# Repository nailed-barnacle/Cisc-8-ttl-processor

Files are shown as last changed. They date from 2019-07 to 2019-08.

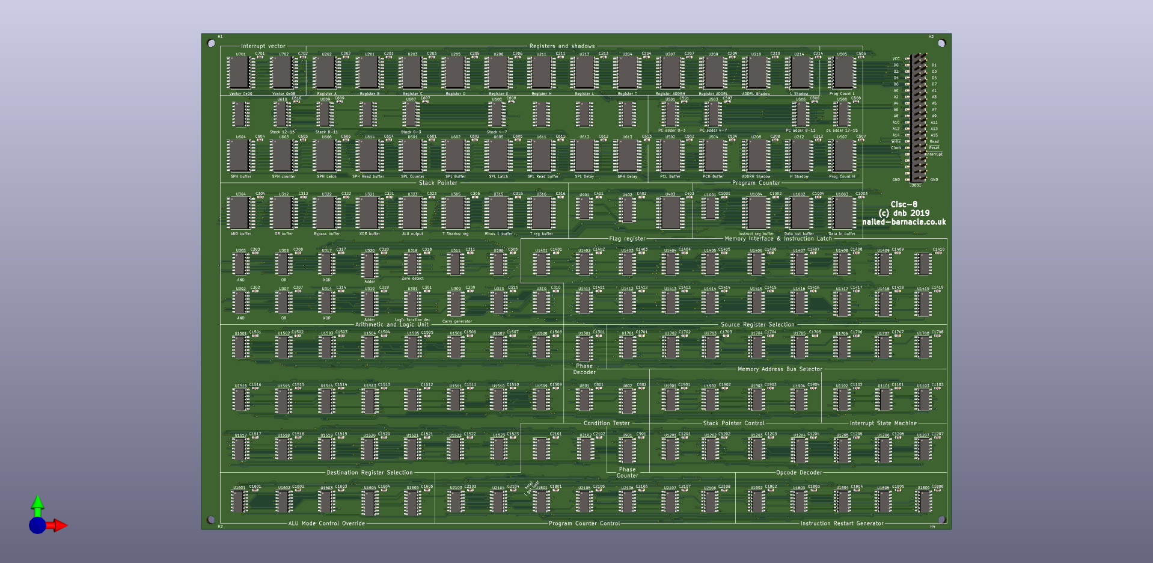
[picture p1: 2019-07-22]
cisc-8.png

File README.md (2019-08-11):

# Cisc-8-ttl-processor
A cut-down version of the 8080 processor using HCTTL and including a discrete ALU and instruction decoder

This is an attempt to replicate most of the functionality of the 1970s Intel 8080 processor using contemporary
HCTTL surface mount components.

By implementing most - though by no means all - of the instructions of the 8080 it allows the use of existing 
toolchains to generate code for the device both for the hardware implementation and the associated simulation.

The programmer's model is the same as the original 8080 - the following instructions are implemented (refer to an 8080 manual for details):

mov add adc sub sbb ana xra ora adi aci sui sbi ani xri ori sphl lxi dad lda sta mvi push pop jmp jnz jz jnc jc call ret 

All other instructions are unimplemented. There are minor changes regarding push/pull, in that push writes to the stack pointer address and then decrements it (and pull increments it and then reads) while the 8080 decrements before pushing. Additionally, it is not possible to mvi to m (hl).

A single non-maskable interrupt is provided, with a hard call to 0x0008 at the end of the current instruction (reset starts at 0x0000)

A two-internal bus model is used, which approximately doubles the speed (in clock cycles) of the original 8080. The longest instruction is the call, which requires 7 cycles.

Provided here are Kicad files for the schematics, Bill of Materials, and the final 200x300mm PCB. The normal
processor interface - data and address bus, power, clock etc are provided through a 40-pin header which would
attach to an adjacent board providing memory, serial port etc.

Recommended for assembling 8080 code in the browser: https://svofski.github.io/pretty-8080-assembler/

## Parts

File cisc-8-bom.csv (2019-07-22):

Source: | /home/barnacle/Projects/Cisc-8/Old/cisc-8 new/cisc-8.sch
Date: | Fri 28 Jun 2019 20:37:52 BST
Tool: | Eeschema 5.1.2-f72e74a~84~ubuntu18.04.1
Generator: | /usr/share/kicad/plugins/bom_csv_grouped_by_value.py
Component Count: | 311
Individual Components:
Item | Qty | Reference(s) | Value | LibPart | Footprint | Datasheet
 |  | C201 | 100n | cisc-8-rescue:C-Device | Capacitor_SMD:C_0603_1608Metric | ~
 |  | C202 | 100n | cisc-8-rescue:C-Device | Capacitor_SMD:C_0603_1608Metric | ~
 |  | C203 | 100n | cisc-8-rescue:C-Device | Capacitor_SMD:C_0603_1608Metric | ~
 |  | C204 | 100n | cisc-8-rescue:C-Device | Capacitor_SMD:C_0603_1608Metric | ~
 |  | C205 | 100n | cisc-8-rescue:C-Device | Capacitor_SMD:C_0603_1608Metric | ~
 |  | C206 | 100n | cisc-8-rescue:C-Device | Capacitor_SMD:C_0603_1608Metric | ~
 |  | C207 | 100n | cisc-8-rescue:C-Device | Capacitor_SMD:C_0603_1608Metric | ~
 |  | C208 | 100n | cisc-8-rescue:C-Device | Capacitor_SMD:C_0603_1608Metric | ~
 |  | C209 | 100n | cisc-8-rescue:C-Device | Capacitor_SMD:C_0603_1608Metric | ~
 |  | C210 | 100n | cisc-8-rescue:C-Device | Capacitor_SMD:C_0603_1608Metric | ~
 |  | C211 | 100n | cisc-8-rescue:C-Device | Capacitor_SMD:C_0603_1608Metric | ~
 |  | C212 | 100n | cisc-8-rescue:C-Device | Capacitor_SMD:C_0603_1608Metric | ~
 |  | C213 | 100n | cisc-8-rescue:C-Device | Capacitor_SMD:C_0603_1608Metric | ~
 |  | C214 | 100n | cisc-8-rescue:C-Device | Capacitor_SMD:C_0603_1608Metric | ~
 |  | C301 | 100n | cisc-8-rescue:C-Device | Capacitor_SMD:C_0603_1608Metric | ~
 |  | C302 | 100n | cisc-8-rescue:C-Device | Capacitor_SMD:C_0603_1608Metric | ~
 |  | C303 | 100n | cisc-8-rescue:C-Device | Capacitor_SMD:C_0603_1608Metric | ~
 |  | C304 | 100n | cisc-8-rescue:C-Device | Capacitor_SMD:C_0603_1608Metric | ~
 |  | C305 | 100n | cisc-8-rescue:C-Device | Capacitor_SMD:C_0603_1608Metric | ~
 |  | C306 | 100n | cisc-8-rescue:C-Device | Capacitor_SMD:C_0603_1608Metric | ~
 |  | C307 | 100n | cisc-8-rescue:C-Device | Capacitor_SMD:C_0603_1608Metric | ~
 |  | C308 | 100n | cisc-8-rescue:C-Device | Capacitor_SMD:C_0603_1608Metric | ~
 |  | C309 | 100n | cisc-8-rescue:C-Device | Capacitor_SMD:C_0603_1608Metric | ~
 |  | C310 | 100n | cisc-8-rescue:C-Device | Capacitor_SMD:C_0603_1608Metric | ~
 |  | C311 | 100n | cisc-8-rescue:C-Device | Capacitor_SMD:C_0603_1608Metric | ~
 |  | C312 | 100n | cisc-8-rescue:C-Device | Capacitor_SMD:C_0603_1608Metric | ~
 |  | C313 | 100n | cisc-8-rescue:C-Device | Capacitor_SMD:C_0603_1608Metric | ~
 |  | C314 | 100n | cisc-8-rescue:C-Device | Capacitor_SMD:C_0603_1608Metric | ~
 |  | C315 | 100n | cisc-8-rescue:C-Device | Capacitor_SMD:C_0603_1608Metric | ~
 |  | C316 | 100n | cisc-8-rescue:C-Device | Capacitor_SMD:C_0603_1608Metric | ~
 |  | C317 | 100n | cisc-8-rescue:C-Device | Capacitor_SMD:C_0603_1608Metric | ~
 |  | C318 | 100n | cisc-8-rescue:C-Device | Capacitor_SMD:C_0603_1608Metric | ~
 |  | C319 | 100n | cisc-8-rescue:C-Device | Capacitor_SMD:C_0603_1608Metric | ~
 |  | C320 | 100n | cisc-8-rescue:C-Device | Capacitor_SMD:C_0603_1608Metric | ~
 |  | C321 | 100n | cisc-8-rescue:C-Device | Capacitor_SMD:C_0603_1608Metric | ~
 |  | C322 | 100n | cisc-8-rescue:C-Device | Capacitor_SMD:C_0603_1608Metric | ~
 |  | C323 | 100n | cisc-8-rescue:C-Device | Capacitor_SMD:C_0603_1608Metric | ~
 |  | C401 | 100n | cisc-8-rescue:C-Device | Capacitor_SMD:C_0603_1608Metric | ~
 |  | C402 | 100n | cisc-8-rescue:C-Device | Capacitor_SMD:C_0603_1608Metric | ~
 |  | C403 | 100n | cisc-8-rescue:C-Device | Capacitor_SMD:C_0603_1608Metric | ~
 |  | C501 | 100n | cisc-8-rescue:C-Device | Capacitor_SMD:C_0603_1608Metric | ~
 |  | C502 | 100n | cisc-8-rescue:C-Device | Capacitor_SMD:C_0603_1608Metric | ~
 |  | C503 | 100n | cisc-8-rescue:C-Device | Capacitor_SMD:C_0603_1608Metric | ~
 |  | C504 | 100n | cisc-8-rescue:C-Device | Capacitor_SMD:C_0603_1608Metric | ~
 |  | C505 | 100n | cisc-8-rescue:C-Device | Capacitor_SMD:C_0603_1608Metric | ~
 |  | C506 | 100n | cisc-8-rescue:C-Device | Capacitor_SMD:C_0603_1608Metric | ~
 |  | C507 | 100n | cisc-8-rescue:C-Device | Capacitor_SMD:C_0603_1608Metric | ~
 |  | C508 | 100n | cisc-8-rescue:C-Device | Capacitor_SMD:C_0603_1608Metric | ~
 |  | C601 | 100n | cisc-8-rescue:C-Device | Capacitor_SMD:C_0603_1608Metric | ~
 |  | C602 | 100n | cisc-8-rescue:C-Device | Capacitor_SMD:C_0603_1608Metric | ~
 |  | C603 | 100n | cisc-8-rescue:C-Device | Capacitor_SMD:C_0603_1608Metric | ~
 |  | C604 | 100n | cisc-8-rescue:C-Device | Capacitor_SMD:C_0603_1608Metric | ~
 |  | C605 | 100n | cisc-8-rescue:C-Device | Capacitor_SMD:C_0603_1608Metric | ~
 |  | C606 | 100n | cisc-8-rescue:C-Device | Capacitor_SMD:C_0603_1608Metric | ~
 |  | C607 | 100n | cisc-8-rescue:C-Device | Capacitor_SMD:C_0603_1608Metric | ~
 |  | C608 | 100n | cisc-8-rescue:C-Device | Capacitor_SMD:C_0603_1608Metric | ~
 |  | C609 | 100n | cisc-8-rescue:C-Device | Capacitor_SMD:C_0603_1608Metric | ~
 |  | C610 | 100n | cisc-8-rescue:C-Device | Capacitor_SMD:C_0603_1608Metric | ~
 |  | C611 | 100n | cisc-8-rescue:C-Device | Capacitor_SMD:C_0603_1608Metric | ~
 |  | C612 | 100n | cisc-8-rescue:C-Device | Capacitor_SMD:C_0603_1608Metric | ~
 |  | C613 | 100n | cisc-8-rescue:C-Device | Capacitor_SMD:C_0603_1608Metric | ~
 |  | C614 | 100n | cisc-8-rescue:C-Device | Capacitor_SMD:C_0603_1608Metric | ~
 |  | C701 | 100n | cisc-8-rescue:C-Device | Capacitor_SMD:C_0603_1608Metric | ~
 |  | C702 | 100n | cisc-8-rescue:C-Device | Capacitor_SMD:C_0603_1608Metric | ~
 |  | C801 | 100n | cisc-8-rescue:C-Device | Capacitor_SMD:C_0603_1608Metric | ~
 |  | C802 | 100n | cisc-8-rescue:C-Device | Capacitor_SMD:C_0603_1608Metric | ~
 |  | C901 | 100n | cisc-8-rescue:C-Device | Capacitor_SMD:C_0603_1608Metric | ~
 |  | C1001 | 100n | cisc-8-rescue:C-Device | Capacitor_SMD:C_0603_1608Metric | ~
 |  | C1002 | 100n | cisc-8-rescue:C-Device | Capacitor_SMD:C_0603_1608Metric | ~
 |  | C1003 | 100n | cisc-8-rescue:C-Device | Capacitor_SMD:C_0603_1608Metric | ~
 |  | C1004 | 100n | cisc-8-rescue:C-Device | Capacitor_SMD:C_0603_1608Metric | ~
 |  | C1101 | 100n | cisc-8-rescue:C-Device | Capacitor_SMD:C_0603_1608Metric | ~
 |  | C1102 | 100n | cisc-8-rescue:C-Device | Capacitor_SMD:C_0603_1608Metric | ~
 |  | C1103 | 100n | cisc-8-rescue:C-Device | Capacitor_SMD:C_0603_1608Metric | ~
 |  | C1201 | 100n | cisc-8-rescue:C-Device | Capacitor_SMD:C_0603_1608Metric | ~
 |  | C1202 | 100n | cisc-8-rescue:C-Device | Capacitor_SMD:C_0603_1608Metric | ~
 |  | C1203 | 100n | cisc-8-rescue:C-Device | Capacitor_SMD:C_0603_1608Metric | ~
 |  | C1204 | 100n | cisc-8-rescue:C-Device | Capacitor_SMD:C_0603_1608Metric | ~
 |  | C1205 | 100n | cisc-8-rescue:C-Device | Capacitor_SMD:C_0603_1608Metric | ~
 |  | C1206 | 100n | cisc-8-rescue:C-Device | Capacitor_SMD:C_0603_1608Metric | ~
 |  | C1207 | 100n | cisc-8-rescue:C-Device | Capacitor_SMD:C_0603_1608Metric | ~
 |  | C1301 | 100n | cisc-8-rescue:C-Device | Capacitor_SMD:C_0603_1608Metric | ~
 |  | C1401 | 100n | cisc-8-rescue:C-Device | Capacitor_SMD:C_0603_1608Metric | ~
 |  | C1402 | 100n | cisc-8-rescue:C-Device | Capacitor_SMD:C_0603_1608Metric | ~
 |  | C1403 | 100n | cisc-8-rescue:C-Device | Capacitor_SMD:C_0603_1608Metric | ~
 |  | C1404 | 100n | cisc-8-rescue:C-Device | Capacitor_SMD:C_0603_1608Metric | ~
 |  | C1405 | 100n | cisc-8-rescue:C-Device | Capacitor_SMD:C_0603_1608Metric | ~
 |  | C1406 | 100n | cisc-8-rescue:C-Device | Capacitor_SMD:C_0603_1608Metric | ~
 |  | C1407 | 100n | cisc-8-rescue:C-Device | Capacitor_SMD:C_0603_1608Metric | ~
 |  | C1408 | 100n | cisc-8-rescue:C-Device | Capacitor_SMD:C_0603_1608Metric | ~
 |  | C1409 | 100n | cisc-8-rescue:C-Device | Capacitor_SMD:C_0603_1608Metric | ~
 |  | C1410 | 100n | cisc-8-rescue:C-Device | Capacitor_SMD:C_0603_1608Metric | ~
 |  | C1411 | 100n | cisc-8-rescue:C-Device | Capacitor_SMD:C_0603_1608Metric | ~
 |  | C1412 | 100n | cisc-8-rescue:C-Device | Capacitor_SMD:C_0603_1608Metric | ~
 |  | C1413 | 100n | cisc-8-rescue:C-Device | Capacitor_SMD:C_0603_1608Metric | ~
 |  | C1414 | 100n | cisc-8-rescue:C-Device | Capacitor_SMD:C_0603_1608Metric | ~
 |  | C1415 | 100n | cisc-8-rescue:C-Device | Capacitor_SMD:C_0603_1608Metric | ~
 |  | C1416 | 100n | cisc-8-rescue:C-Device | Capacitor_SMD:C_0603_1608Metric | ~
 |  | C1417 | 100n | cisc-8-rescue:C-Device | Capacitor_SMD:C_0603_1608Metric | ~
 |  | C1418 | 100n | cisc-8-rescue:C-Device | Capacitor_SMD:C_0603_1608Metric | ~
 |  | C1419 | 100n | cisc-8-rescue:C-Device | Capacitor_SMD:C_0603_1608Metric | ~
 |  | C1501 | 100n | cisc-8-rescue:C-Device | Capacitor_SMD:C_0603_1608Metric | ~
 |  | C1502 | 100n | cisc-8-rescue:C-Device | Capacitor_SMD:C_0603_1608Metric | ~
 |  | C1503 | 100n | cisc-8-rescue:C-Device | Capacitor_SMD:C_0603_1608Metric | ~
 |  | C1504 | 100n | cisc-8-rescue:C-Device | Capacitor_SMD:C_0603_1608Metric | ~
 |  | C1505 | 100n | cisc-8-rescue:C-Device | Capacitor_SMD:C_0603_1608Metric | ~
 |  | C1506 | 100n | cisc-8-rescue:C-Device | Capacitor_SMD:C_0603_1608Metric | ~
 |  | C1507 | 100n | cisc-8-rescue:C-Device | Capacitor_SMD:C_0603_1608Metric | ~
 |  | C1508 | 100n | cisc-8-rescue:C-Device | Capacitor_SMD:C_0603_1608Metric | ~
 |  | C1509 | 100n | cisc-8-rescue:C-Device | Capacitor_SMD:C_0603_1608Metric | ~
 |  | C1510 | 100n | cisc-8-rescue:C-Device | Capacitor_SMD:C_0603_1608Metric | ~
 |  | C1511 | 100n | cisc-8-rescue:C-Device | Capacitor_SMD:C_0603_1608Metric | ~
 |  | C1512 | 100n | cisc-8-rescue:C-Device | Capacitor_SMD:C_0603_1608Metric | ~
 |  | C1513 | 100n | cisc-8-rescue:C-Device | Capacitor_SMD:C_0603_1608Metric | ~
 |  | C1514 | 100n | cisc-8-rescue:C-Device | Capacitor_SMD:C_0603_1608Metric | ~
 |  | C1515 | 100n | cisc-8-rescue:C-Device | Capacitor_SMD:C_0603_1608Metric | ~
 |  | C1516 | 100n | cisc-8-rescue:C-Device | Capacitor_SMD:C_0603_1608Metric | ~
 |  | C1517 | 100n | cisc-8-rescue:C-Device | Capacitor_SMD:C_0603_1608Metric | ~
 |  | C1518 | 100n | cisc-8-rescue:C-Device | Capacitor_SMD:C_0603_1608Metric | ~
 |  | C1519 | 100n | cisc-8-rescue:C-Device | Capacitor_SMD:C_0603_1608Metric | ~
 |  | C1520 | 100n | cisc-8-rescue:C-Device | Capacitor_SMD:C_0603_1608Metric | ~
 |  | C1521 | 100n | cisc-8-rescue:C-Device | Capacitor_SMD:C_0603_1608Metric | ~
 |  | C1522 | 100n | cisc-8-rescue:C-Device | Capacitor_SMD:C_0603_1608Metric | ~
 |  | C1523 | 100n | cisc-8-rescue:C-Device | Capacitor_SMD:C_0603_1608Metric | ~
 |  | C1601 | 100n | cisc-8-rescue:C-Device | Capacitor_SMD:C_0603_1608Metric | ~
 |  | C1602 | 100n | cisc-8-rescue:C-Device | Capacitor_SMD:C_0603_1608Metric | ~
 |  | C1603 | 100n | cisc-8-rescue:C-Device | Capacitor_SMD:C_0603_1608Metric | ~
 |  | C1604 | 100n | cisc-8-rescue:C-Device | Capacitor_SMD:C_0603_1608Metric | ~
 |  | C1605 | 100n | cisc-8-rescue:C-Device | Capacitor_SMD:C_0603_1608Metric | ~
 |  | C1701 | 100n | cisc-8-rescue:C-Device | Capacitor_SMD:C_0603_1608Metric | ~
 |  | C1702 | 100n | cisc-8-rescue:C-Device | Capacitor_SMD:C_0603_1608Metric | ~
 |  | C1703 | 100n | cisc-8-rescue:C-Device | Capacitor_SMD:C_0603_1608Metric | ~
 |  | C1704 | 100n | cisc-8-rescue:C-Device | Capacitor_SMD:C_0603_1608Metric | ~
 |  | C1705 | 100n | cisc-8-rescue:C-Device | Capacitor_SMD:C_0603_1608Metric | ~
 |  | C1706 | 100n | cisc-8-rescue:C-Device | Capacitor_SMD:C_0603_1608Metric | ~
 |  | C1707 | 100n | cisc-8-rescue:C-Device | Capacitor_SMD:C_0603_1608Metric | ~
 |  | C1708 | 100n | cisc-8-rescue:C-Device | Capacitor_SMD:C_0603_1608Metric | ~
 |  | C1801 | 100n | cisc-8-rescue:C-Device | Capacitor_SMD:C_0603_1608Metric | ~
 |  | C1802 | 100n | cisc-8-rescue:C-Device | Capacitor_SMD:C_0603_1608Metric | ~
 |  | C1803 | 100n | cisc-8-rescue:C-Device | Capacitor_SMD:C_0603_1608Metric | ~
 |  | C1804 | 100n | cisc-8-rescue:C-Device | Capacitor_SMD:C_0603_1608Metric | ~
 |  | C1805 | 100n | cisc-8-rescue:C-Device | Capacitor_SMD:C_0603_1608Metric | ~
 |  | C1806 | 100n | cisc-8-rescue:C-Device | Capacitor_SMD:C_0603_1608Metric | ~
 |  | C1901 | 100n | cisc-8-rescue:C-Device | Capacitor_SMD:C_0603_1608Metric | ~
 |  | C1902 | 100n | cisc-8-rescue:C-Device | Capacitor_SMD:C_0603_1608Metric | ~
 |  | C1903 | 100n | cisc-8-rescue:C-Device | Capacitor_SMD:C_0603_1608Metric | ~
 |  | C1904 | 100n | cisc-8-rescue:C-Device | Capacitor_SMD:C_0603_1608Metric | ~
 |  | C2101 | 100n | cisc-8-rescue:C-Device | Capacitor_SMD:C_0603_1608Metric | ~
 |  | C2102 | 100n | cisc-8-rescue:C-Device | Capacitor_SMD:C_0603_1608Metric | ~
 |  | C2103 | 100n | cisc-8-rescue:C-Device | Capacitor_SMD:C_0603_1608Metric | ~
 |  | C2104 | 100n | cisc-8-rescue:C-Device | Capacitor_SMD:C_0603_1608Metric | ~
 |  | C2105 | 100n | cisc-8-rescue:C-Device | Capacitor_SMD:C_0603_1608Metric | ~
 |  | C2106 | 100n | cisc-8-rescue:C-Device | Capacitor_SMD:C_0603_1608Metric | ~
 |  | C2107 | 100n | cisc-8-rescue:C-Device | Capacitor_SMD:C_0603_1608Metric | ~
 |  | C2108 | 100n | cisc-8-rescue:C-Device | Capacitor_SMD:C_0603_1608Metric | ~
 |  | J2001 | Conn_02x20_Odd_Even | Connector_Generic:Conn_02x20_Odd_Even | Connector_PinHeader_2.54mm:PinHeader_2x20_P2.54mm_Vertical_SMD | ~
 |  | U201 | 74HC574 | cisc-8-rescue:74HCT574-74xx | Package_SO:SOIC-20W_7.5x12.8mm_P1.27mm
 |  | U202 | 74HC574 | cisc-8-rescue:74HCT574-74xx | Package_SO:SOIC-20W_7.5x12.8mm_P1.27mm
 |  | U203 | 74HC574 | cisc-8-rescue:74HCT574-74xx | Package_SO:SOIC-20W_7.5x12.8mm_P1.27mm
 |  | U204 | 74HC574 | cisc-8-rescue:74HCT574-74xx | Package_SO:SOIC-20W_7.5x12.8mm_P1.27mm
 |  | U205 | 74HC574 | cisc-8-rescue:74HCT574-74xx | Package_SO:SOIC-20W_7.5x12.8mm_P1.27mm
 |  | U206 | 74HC574 | cisc-8-rescue:74HCT574-74xx | Package_SO:SOIC-20W_7.5x12.8mm_P1.27mm
 |  | U207 | 74HC574 | cisc-8-rescue:74HCT574-74xx | Package_SO:SOIC-20W_7.5x12.8mm_P1.27mm
 |  | U208 | 74HC574 | cisc-8-rescue:74HCT574-74xx | Package_SO:SOIC-20W_7.5x12.8mm_P1.27mm
 |  | U209 | 74HC574 | cisc-8-rescue:74HCT574-74xx | Package_SO:SOIC-20W_7.5x12.8mm_P1.27mm
 |  | U210 | 74HC574 | cisc-8-rescue:74HCT574-74xx | Package_SO:SOIC-20W_7.5x12.8mm_P1.27mm
 |  | U211 | 74HC574 | cisc-8-rescue:74HCT574-74xx | Package_SO:SOIC-20W_7.5x12.8mm_P1.27mm
 |  | U212 | 74HC574 | cisc-8-rescue:74HCT574-74xx | Package_SO:SOIC-20W_7.5x12.8mm_P1.27mm
 |  | U213 | 74HC574 | cisc-8-rescue:74HCT574-74xx | Package_SO:SOIC-20W_7.5x12.8mm_P1.27mm
 |  | U214 | 74HC574 | cisc-8-rescue:74HCT574-74xx | Package_SO:SOIC-20W_7.5x12.8mm_P1.27mm
 |  | U301 | 74HC138 | cisc-8-rescue:74LS138-74xx | Package_SO:SOIC-16_3.9x9.9mm_P1.27mm | http://www.ti.com/lit/gpn/sn74LS138
 |  | U302 | 74HC08 | cisc-8-rescue:74LS08-74xx | Package_SO:SOIC-14_3.9x8.7mm_P1.27mm | http://www.ti.com/lit/gpn/sn74LS08
 |  | U303 | 74HC08 | cisc-8-rescue:74LS08-74xx | Package_SO:SOIC-14_3.9x8.7mm_P1.27mm | http://www.ti.com/lit/gpn/sn74LS08
 |  | U304 | 74HC541 | cisc-8-rescue:74HCT541-74xx | Package_SO:SOIC-20W_7.5x12.8mm_P1.27mm | http://www.ti.com/lit/gpn/sn74HCT541
 |  | U305 | 74HC574 | cisc-8-rescue:74HCT574-74xx | Package_SO:SOIC-20W_7.5x12.8mm_P1.27mm | http://www.ti.com/lit/gpn/sn74HCT574
 |  | U306 | 74HC08 | cisc-8-rescue:74LS08-74xx | Package_SO:SOIC-14_3.9x8.7mm_P1.27mm | http://www.ti.com/lit/gpn/sn74LS08
 |  | U307 | 74HC32 | cisc-8-rescue:74LS32-74xx | Package_SO:SOIC-14_3.9x8.7mm_P1.27mm | http://www.ti.com/lit/gpn/sn74LS32
 |  | U308 | 74HC32 | cisc-8-rescue:74LS32-74xx | Package_SO:SOIC-14_3.9x8.7mm_P1.27mm | http://www.ti.com/lit/gpn/sn74LS32
 |  | U309 | 74HC238 | cisc-8-rescue:74HC238-74xx_IEEE | Package_SO:SOIC-16_3.9x9.9mm_P1.27mm
 |  | U310 | 74HC32 | cisc-8-rescue:74LS32-74xx | Package_SO:SOIC-14_3.9x8.7mm_P1.27mm | http://www.ti.com/lit/gpn/sn74LS32
 |  | U311 | 74HC04 | cisc-8-rescue:74HC04-74xx | Package_SO:SOIC-14_3.9x8.7mm_P1.27mm | http://www.nxp.com/documents/data_sheet/74HC_HCT04.pdf
 |  | U312 | 74HC541 | cisc-8-rescue:74HCT541-74xx | Package_SO:SOIC-20W_7.5x12.8mm_P1.27mm | http://www.ti.com/lit/gpn/sn74HCT541
 |  | U313 | 74HC4075 | cisc-8-rescue:4075-4xxx_IEEE | Package_SO:SOIC-14_3.9x8.7mm_P1.27mm
 |  | U314 | 74HC86 | cisc-8-rescue:74HC86-74xx | Package_SO:SOIC-14_3.9x8.7mm_P1.27mm | http://www.ti.com/lit/gpn/sn74HC86
 |  | U315 | 74HC541 | cisc-8-rescue:74HCT541-74xx | Package_SO:SOIC-20W_7.5x12.8mm_P1.27mm | http://www.ti.com/lit/gpn/sn74HCT541
 |  | U316 | 74HC541 | cisc-8-rescue:74HCT541-74xx | Package_SO:SOIC-20W_7.5x12.8mm_P1.27mm | http://www.ti.com/lit/gpn/sn74HCT541
 |  | U317 | 74HC86 | cisc-8-rescue:74HC86-74xx | Package_SO:SOIC-14_3.9x8.7mm_P1.27mm | http://www.ti.com/lit/gpn/sn74HC86
 |  | U318 | 74HC4002 | cisc-8-rescue:4002-4xxx | Package_SO:SOIC-14_3.9x8.7mm_P1.27mm | http://www.intersil.com/content/dam/Intersil/documents/cd40/cd4000bms-01bms-02bms-25bms.pdf
 |  | U319 | 74HC283 | cisc-8-rescue:74LS283-74xx | Package_SO:SOIC-16_3.9x9.9mm_P1.27mm | http://www.ti.com/lit/gpn/sn74LS283
 |  | U320 | 74HC283 | cisc-8-rescue:74LS283-74xx | Package_SO:SOIC-16_3.9x9.9mm_P1.27mm | http://www.ti.com/lit/gpn/sn74LS283
 |  | U321 | 74HC541 | cisc-8-rescue:74HCT541-74xx | Package_SO:SOIC-20W_7.5x12.8mm_P1.27mm | http://www.ti.com/lit/gpn/sn74HCT541
 |  | U322 | 74HC541 | cisc-8-rescue:74HCT541-74xx | Package_SO:SOIC-20W_7.5x12.8mm_P1.27mm | http://www.ti.com/lit/gpn/sn74HCT541
 |  | U323 | 74HC541 | cisc-8-rescue:74HCT541-74xx | Package_SO:SOIC-20W_7.5x12.8mm_P1.27mm | http://www.ti.com/lit/gpn/sn74HCT541
 |  | U401 | 74HC74 | cisc-8-rescue:74HC74-74xx | Package_SO:SOIC-14_3.9x8.7mm_P1.27mm | 74xx/74hc_hct74.pdf
 |  | U402 | 74HC157 | cisc-8-rescue:74LS157-74xx | Package_SO:SOIC-16_3.9x9.9mm_P1.27mm | http://www.ti.com/lit/gpn/sn74LS157
 |  | U403 | 74HC541 | cisc-8-rescue:74HCT541-74xx | Package_SO:SOIC-20W_7.5x12.8mm_P1.27mm | http://www.ti.com/lit/gpn/sn74HCT541
 |  | U501 | 74HC163 | cisc-8-rescue:74LS163-74xx | Package_SO:SOIC-16_3.9x9.9mm_P1.27mm | http://www.ti.com/lit/gpn/sn74LS163
 |  | U502 | 74HC541 | cisc-8-rescue:74HCT541-74xx | Package_SO:SOIC-20W_7.5x12.8mm_P1.27mm | http://www.ti.com/lit/gpn/sn74HCT541
 |  | U503 | 74HC163 | cisc-8-rescue:74LS163-74xx | Package_SO:SOIC-16_3.9x9.9mm_P1.27mm | http://www.ti.com/lit/gpn/sn74LS163
 |  | U504 | 74HC541 | cisc-8-rescue:74HCT541-74xx | Package_SO:SOIC-20W_7.5x12.8mm_P1.27mm | http://www.ti.com/lit/gpn/sn74HCT541
 |  | U505 | 74HC574 | cisc-8-rescue:74HCT574-74xx | Package_SO:SOIC-20W_7.5x12.8mm_P1.27mm | http://www.ti.com/lit/gpn/sn74HCT574
 |  | U506 | 74HC163 | cisc-8-rescue:74LS163-74xx | Package_SO:SOIC-16_3.9x9.9mm_P1.27mm | http://www.ti.com/lit/gpn/sn74LS163
 |  | U507 | 74HC574 | cisc-8-rescue:74HCT574-74xx | Package_SO:SOIC-20W_7.5x12.8mm_P1.27mm | http://www.ti.com/lit/gpn/sn74HCT574
 |  | U508 | 74HC163 | cisc-8-rescue:74LS163-74xx | Package_SO:SOIC-16_3.9x9.9mm_P1.27mm | http://www.ti.com/lit/gpn/sn74LS163
 |  | U601 | 74HC541 | cisc-8-rescue:74HCT541-74xx | Package_SO:SOIC-20W_7.5x12.8mm_P1.27mm | http://www.ti.com/lit/gpn/sn74HCT541
 |  | U602 | 74HC541 | cisc-8-rescue:74HCT541-74xx | Package_SO:SOIC-20W_7.5x12.8mm_P1.27mm | http://www.ti.com/lit/gpn/sn74HCT541
 |  | U603 | 74HC541 | cisc-8-rescue:74HCT541-74xx | Package_SO:SOIC-20W_7.5x12.8mm_P1.27mm | http://www.ti.com/lit/gpn/sn74HCT541
 |  | U604 | 74HC541 | cisc-8-rescue:74HCT541-74xx | Package_SO:SOIC-20W_7.5x12.8mm_P1.27mm | http://www.ti.com/lit/gpn/sn74HCT541
 |  | U605 | 74HC574 | cisc-8-rescue:74HCT574-74xx | Package_SO:SOIC-20W_7.5x12.8mm_P1.27mm | http://www.ti.com/lit/gpn/sn74HCT574
 |  | U606 | 74HC574 | cisc-8-rescue:74HCT574-74xx | Package_SO:SOIC-20W_7.5x12.8mm_P1.27mm | http://www.ti.com/lit/gpn/sn74HCT574
 |  | U607 | 74HC283 | cisc-8-rescue:74LS283-74xx | Package_SO:SOIC-16_3.9x9.9mm_P1.27mm | http://www.ti.com/lit/gpn/sn74LS283
 |  | U608 | 74HC283 | cisc-8-rescue:74LS283-74xx | Package_SO:SOIC-16_3.9x9.9mm_P1.27mm | http://www.ti.com/lit/gpn/sn74LS283
 |  | U609 | 74HC283 | cisc-8-rescue:74LS283-74xx | Package_SO:SOIC-16_3.9x9.9mm_P1.27mm | http://www.ti.com/lit/gpn/sn74LS283
 |  | U610 | 74HC283 | cisc-8-rescue:74LS283-74xx | Package_SO:SOIC-16_3.9x9.9mm_P1.27mm | http://www.ti.com/lit/gpn/sn74LS283
 |  | U611 | 74HC541 | cisc-8-rescue:74HCT541-74xx | Package_SO:SOIC-20W_7.5x12.8mm_P1.27mm | http://www.ti.com/lit/gpn/sn74HCT541
 |  | U612 | 74HC574 | cisc-8-rescue:74HCT574-74xx | Package_SO:SOIC-20W_7.5x12.8mm_P1.27mm | http://www.ti.com/lit/gpn/sn74HCT574
 |  | U613 | 74HC574 | cisc-8-rescue:74HCT574-74xx | Package_SO:SOIC-20W_7.5x12.8mm_P1.27mm | http://www.ti.com/lit/gpn/sn74HCT574
 |  | U614 | 74HC541 | cisc-8-rescue:74HCT541-74xx | Package_SO:SOIC-20W_7.5x12.8mm_P1.27mm | http://www.ti.com/lit/gpn/sn74HCT541
 |  | U701 | 74HC541 | cisc-8-rescue:74HCT541-74xx | Package_SO:SOIC-20W_7.5x12.8mm_P1.27mm | http://www.ti.com/lit/gpn/sn74HCT541
 |  | U702 | 74HC541 | cisc-8-rescue:74HCT541-74xx | Package_SO:SOIC-20W_7.5x12.8mm_P1.27mm | http://www.ti.com/lit/gpn/sn74HCT541
 |  | U801 | 74HC86 | cisc-8-rescue:74HC86-74xx | Package_SO:SOIC-14_3.9x8.7mm_P1.27mm | http://www.ti.com/lit/gpn/sn74HC86
 |  | U802 | 74HC157 | cisc-8-rescue:74LS157-74xx | Package_SO:SOIC-16_3.9x9.9mm_P1.27mm | http://www.ti.com/lit/gpn/sn74LS157
 |  | U901 | 74HC163 | cisc-8-rescue:74LS163-74xx | Package_SO:SOIC-16_3.9x9.9mm_P1.27mm | http://www.ti.com/lit/gpn/sn74LS163
 |  | U1001 | 74HC04 | cisc-8-rescue:74HC04-74xx | Package_SO:SOIC-14_3.9x8.7mm_P1.27mm | http://www.nxp.com/documents/data_sheet/74HC_HCT04.pdf
 |  | U1002 | 74HC541 | cisc-8-rescue:74HCT541-74xx | Package_SO:SOIC-20W_7.5x12.8mm_P1.27mm | http://www.ti.com/lit/gpn/sn74HCT541
 |  | U1003 | 74HC541 | cisc-8-rescue:74HCT541-74xx | Package_SO:SOIC-20W_7.5x12.8mm_P1.27mm | http://www.ti.com/lit/gpn/sn74HCT541
 |  | U1004 | 74HC541 | cisc-8-rescue:74HCT541-74xx | Package_SO:SOIC-20W_7.5x12.8mm_P1.27mm | http://www.ti.com/lit/gpn/sn74HCT541
 |  | U1101 | 74HC74 | cisc-8-rescue:74HC74-74xx | Package_SO:SOIC-14_3.9x8.7mm_P1.27mm | 74xx/74hc_hct74.pdf
 |  | U1102 | 74HC27 | cisc-8-rescue:74LS27-74xx | Package_SO:SOIC-14_3.9x8.7mm_P1.27mm | http://www.ti.com/lit/gpn/sn74LS27
 |  | U1103 | 74HC08 | cisc-8-rescue:74LS08-74xx | Package_SO:SOIC-14_3.9x8.7mm_P1.27mm | http://www.ti.com/lit/gpn/sn74LS08
 |  | U1201 | 74HC11 | cisc-8-rescue:74LS11-74xx | Package_SO:SOIC-14_3.9x8.7mm_P1.27mm | http://www.ti.com/lit/gpn/sn74LS11
 |  | U1202 | 74HC11 | cisc-8-rescue:74LS11-74xx | Package_SO:SOIC-14_3.9x8.7mm_P1.27mm | http://www.ti.com/lit/gpn/sn74LS11
 |  | U1203 | 74HC11 | cisc-8-rescue:74LS11-74xx | Package_SO:SOIC-14_3.9x8.7mm_P1.27mm | http://www.ti.com/lit/gpn/sn74LS11
 |  | U1204 | 74HC238 | cisc-8-rescue:74HC238-74xx_IEEE | Package_SO:SOIC-16_3.9x9.9mm_P1.27mm
 |  | U1205 | 74HC238 | cisc-8-rescue:74HC238-74xx_IEEE | Package_SO:SOIC-16_3.9x9.9mm_P1.27mm
 |  | U1206 | 74HC238 | cisc-8-rescue:74HC238-74xx_IEEE | Package_SO:SOIC-16_3.9x9.9mm_P1.27mm
 |  | U1207 | 74HC11 | cisc-8-rescue:74LS11-74xx | Package_SO:SOIC-14_3.9x8.7mm_P1.27mm | http://www.ti.com/lit/gpn/sn74LS11
 |  | U1301 | 74HC238 | cisc-8-rescue:74HC238-74xx_IEEE | Package_SO:SOIC-16_3.9x9.9mm_P1.27mm
 |  | U1401 | 74HC00 | cisc-8-rescue:74HC00-74xx | Package_SO:SOIC-14_3.9x8.7mm_P1.27mm | http://www.ti.com/lit/gpn/sn74hc00
 |  | U1402 | 74HC02 | cisc-8-rescue:7402-74xx | Package_SO:SOIC-14_3.9x8.7mm_P1.27mm | http://www.ti.com/lit/gpn/sn7402
 |  | U1403 | 74HC08 | cisc-8-rescue:74LS08-74xx | Package_SO:SOIC-14_3.9x8.7mm_P1.27mm | http://www.ti.com/lit/gpn/sn74LS08
 |  | U1404 | 74HC32 | cisc-8-rescue:74LS32-74xx | Package_SO:SOIC-14_3.9x8.7mm_P1.27mm | http://www.ti.com/lit/gpn/sn74LS32
 |  | U1405 | 74HC08 | cisc-8-rescue:74LS08-74xx | Package_SO:SOIC-14_3.9x8.7mm_P1.27mm | http://www.ti.com/lit/gpn/sn74LS08
 |  | U1406 | 74HC08 | cisc-8-rescue:74LS08-74xx | Package_SO:SOIC-14_3.9x8.7mm_P1.27mm | http://www.ti.com/lit/gpn/sn74LS08
 |  | U1407 | 74HC08 | cisc-8-rescue:74LS08-74xx | Package_SO:SOIC-14_3.9x8.7mm_P1.27mm | http://www.ti.com/lit/gpn/sn74LS08
 |  | U1408 | 74HC08 | cisc-8-rescue:74LS08-74xx | Package_SO:SOIC-14_3.9x8.7mm_P1.27mm | http://www.ti.com/lit/gpn/sn74LS08
 |  | U1409 | 74HC04 | cisc-8-rescue:74HC04-74xx | Package_SO:SOIC-14_3.9x8.7mm_P1.27mm | http://www.nxp.com/documents/data_sheet/74HC_HCT04.pdf
 |  | U1410 | 74HC04 | cisc-8-rescue:74HC04-74xx | Package_SO:SOIC-14_3.9x8.7mm_P1.27mm | http://www.nxp.com/documents/data_sheet/74HC_HCT04.pdf
 |  | U1411 | 74HC32 | cisc-8-rescue:74LS32-74xx | Package_SO:SOIC-14_3.9x8.7mm_P1.27mm | http://www.ti.com/lit/gpn/sn74LS32
 |  | U1412 | 74HC08 | cisc-8-rescue:74LS08-74xx | Package_SO:SOIC-14_3.9x8.7mm_P1.27mm | http://www.ti.com/lit/gpn/sn74LS08
 |  | U1413 | 74HC32 | cisc-8-rescue:74LS32-74xx | Package_SO:SOIC-14_3.9x8.7mm_P1.27mm | http://www.ti.com/lit/gpn/sn74LS32
 |  | U1414 | 74HC27 | cisc-8-rescue:74LS27-74xx | Package_SO:SOIC-14_3.9x8.7mm_P1.27mm | http://www.ti.com/lit/gpn/sn74LS27
 |  | U1415 | 74HC27 | cisc-8-rescue:74LS27-74xx | Package_SO:SOIC-14_3.9x8.7mm_P1.27mm | http://www.ti.com/lit/gpn/sn74LS27
 |  | U1416 | 74HC4075 | cisc-8-rescue:4075-4xxx_IEEE | Package_SO:SOIC-14_3.9x8.7mm_P1.27mm
 |  | U1417 | 74HC238 | cisc-8-rescue:74HC238-74xx_IEEE | Package_SO:SOIC-16_3.9x9.9mm_P1.27mm
 |  | U1418 | 74HC238 | cisc-8-rescue:74HC238-74xx_IEEE | Package_SO:SOIC-16_3.9x9.9mm_P1.27mm
 |  | U1419 | 74HC238 | cisc-8-rescue:74HC238-74xx_IEEE | Package_SO:SOIC-16_3.9x9.9mm_P1.27mm
 |  | U1501 | 74HC32 | cisc-8-rescue:74LS32-74xx | Package_SO:SOIC-14_3.9x8.7mm_P1.27mm | http://www.ti.com/lit/gpn/sn74LS32
 |  | U1502 | 74HC08 | cisc-8-rescue:74LS08-74xx | Package_SO:SOIC-14_3.9x8.7mm_P1.27mm | http://www.ti.com/lit/gpn/sn74LS08
 |  | U1503 | 74HC4075 | cisc-8-rescue:4075-4xxx_IEEE | Package_SO:SOIC-14_3.9x8.7mm_P1.27mm
 |  | U1504 | 74HC4075 | cisc-8-rescue:4075-4xxx_IEEE | Package_SO:SOIC-14_3.9x8.7mm_P1.27mm
 |  | U1505 | 74HC08 | cisc-8-rescue:74LS08-74xx | Package_SO:SOIC-14_3.9x8.7mm_P1.27mm | http://www.ti.com/lit/gpn/sn74LS08
 |  | U1506 | 74HC08 | cisc-8-rescue:74LS08-74xx | Package_SO:SOIC-14_3.9x8.7mm_P1.27mm | http://www.ti.com/lit/gpn/sn74LS08
 |  | U1507 | 74HC08 | cisc-8-rescue:74LS08-74xx | Package_SO:SOIC-14_3.9x8.7mm_P1.27mm | http://www.ti.com/lit/gpn/sn74LS08
 |  | U1508 | 74HC4075 | cisc-8-rescue:4075-4xxx_IEEE | Package_SO:SOIC-14_3.9x8.7mm_P1.27mm
 |  | U1509 | 74HC32 | cisc-8-rescue:74LS32-74xx | Package_SO:SOIC-14_3.9x8.7mm_P1.27mm | http://www.ti.com/lit/gpn/sn74LS32
 |  | U1510 | 74HC08 | cisc-8-rescue:74LS08-74xx | Package_SO:SOIC-14_3.9x8.7mm_P1.27mm | http://www.ti.com/lit/gpn/sn74LS08
 |  | U1511 | 74HC08 | cisc-8-rescue:74LS08-74xx | Package_SO:SOIC-14_3.9x8.7mm_P1.27mm | http://www.ti.com/lit/gpn/sn74LS08
 |  | U1512 | 74HC04 | cisc-8-rescue:74HC04-74xx | Package_SO:SOIC-14_3.9x8.7mm_P1.27mm | http://www.nxp.com/documents/data_sheet/74HC_HCT04.pdf
 |  | U1513 | 74HC238 | cisc-8-rescue:74HC238-74xx_IEEE | Package_SO:SOIC-16_3.9x9.9mm_P1.27mm
 |  | U1514 | 74HC238 | cisc-8-rescue:74HC238-74xx_IEEE | Package_SO:SOIC-16_3.9x9.9mm_P1.27mm
 |  | U1515 | 74HC238 | cisc-8-rescue:74HC238-74xx_IEEE | Package_SO:SOIC-16_3.9x9.9mm_P1.27mm
 |  | U1516 | 74HC32 | cisc-8-rescue:74LS32-74xx | Package_SO:SOIC-14_3.9x8.7mm_P1.27mm | http://www.ti.com/lit/gpn/sn74LS32
 |  | U1517 | 74HC4075 | cisc-8-rescue:4075-4xxx_IEEE | Package_SO:SOIC-14_3.9x8.7mm_P1.27mm
 |  | U1518 | 74HC32 | cisc-8-rescue:74LS32-74xx | Package_SO:SOIC-14_3.9x8.7mm_P1.27mm | http://www.ti.com/lit/gpn/sn74LS32
 |  | U1519 | 74HC08 | cisc-8-rescue:74LS08-74xx | Package_SO:SOIC-14_3.9x8.7mm_P1.27mm | http://www.ti.com/lit/gpn/sn74LS08
 |  | U1520 | 74HC08 | cisc-8-rescue:74LS08-74xx | Package_SO:SOIC-14_3.9x8.7mm_P1.27mm | http://www.ti.com/lit/gpn/sn74LS08
 |  | U1521 | 74HC08 | cisc-8-rescue:74LS08-74xx | Package_SO:SOIC-14_3.9x8.7mm_P1.27mm | http://www.ti.com/lit/gpn/sn74LS08
 |  | U1522 | 74HC08 | cisc-8-rescue:74LS08-74xx | Package_SO:SOIC-14_3.9x8.7mm_P1.27mm | http://www.ti.com/lit/gpn/sn74LS08
 |  | U1523 | 74HC02 | cisc-8-rescue:7402-74xx | Package_SO:SOIC-14_3.9x8.7mm_P1.27mm | http://www.ti.com/lit/gpn/sn7402
 |  | U1601 | 74HC08 | cisc-8-rescue:74LS08-74xx | Package_SO:SOIC-14_3.9x8.7mm_P1.27mm | http://www.ti.com/lit/gpn/sn74LS08
 |  | U1602 | 74HC32 | cisc-8-rescue:74LS32-74xx | Package_SO:SOIC-14_3.9x8.7mm_P1.27mm | http://www.ti.com/lit/gpn/sn74LS32
 |  | U1603 | 74HC04 | cisc-8-rescue:74HC04-74xx | Package_SO:SOIC-14_3.9x8.7mm_P1.27mm | http://www.nxp.com/documents/data_sheet/74HC_HCT04.pdf
 |  | U1604 | 74HC157 | cisc-8-rescue:74LS157-74xx | Package_SO:SOIC-16_3.9x9.9mm_P1.27mm | http://www.ti.com/lit/gpn/sn74LS157
 |  | U1605 | 74HC157 | cisc-8-rescue:74LS157-74xx | Package_SO:SOIC-16_3.9x9.9mm_P1.27mm | http://www.ti.com/lit/gpn/sn74LS157
 |  | U1701 | 74HC08 | cisc-8-rescue:74LS08-74xx | Package_SO:SOIC-14_3.9x8.7mm_P1.27mm | http://www.ti.com/lit/gpn/sn74LS08
 |  | U1702 | 74HC32 | cisc-8-rescue:74LS32-74xx | Package_SO:SOIC-14_3.9x8.7mm_P1.27mm | http://www.ti.com/lit/gpn/sn74LS32
 |  | U1703 | 74HC4075 | cisc-8-rescue:4075-4xxx_IEEE | Package_SO:SOIC-14_3.9x8.7mm_P1.27mm
 |  | U1704 | 74HC08 | cisc-8-rescue:74LS08-74xx | Package_SO:SOIC-14_3.9x8.7mm_P1.27mm | http://www.ti.com/lit/gpn/sn74LS08
 |  | U1705 | 74HC02 | cisc-8-rescue:7402-74xx | Package_SO:SOIC-14_3.9x8.7mm_P1.27mm | http://www.ti.com/lit/gpn/sn7402
 |  | U1706 | 74HC00 | cisc-8-rescue:74HC00-74xx | Package_SO:SOIC-14_3.9x8.7mm_P1.27mm | http://www.ti.com/lit/gpn/sn74hc00
 |  | U1707 | 74HC27 | cisc-8-rescue:74LS27-74xx | Package_SO:SOIC-14_3.9x8.7mm_P1.27mm | http://www.ti.com/lit/gpn/sn74LS27
 |  | U1708 | 74HC10 | cisc-8-rescue:74LS10-74xx | Package_SO:SOIC-14_3.9x8.7mm_P1.27mm | http://www.ti.com/lit/gpn/sn74LS10
 |  | U1801 | 74HC4075 | cisc-8-rescue:4075-4xxx_IEEE | Package_SO:SOIC-14_3.9x8.7mm_P1.27mm
 |  | U1802 | 74HC4075 | cisc-8-rescue:4075-4xxx_IEEE | Package_SO:SOIC-14_3.9x8.7mm_P1.27mm
 |  | U1803 | 74HC08 | cisc-8-rescue:74LS08-74xx | Package_SO:SOIC-14_3.9x8.7mm_P1.27mm | http://www.ti.com/lit/gpn/sn74LS08
 |  | U1804 | 74HC32 | cisc-8-rescue:74LS32-74xx | Package_SO:SOIC-14_3.9x8.7mm_P1.27mm | http://www.ti.com/lit/gpn/sn74LS32
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

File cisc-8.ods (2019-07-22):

Id | Designator | Package | Quantity | Designation | Digikey |  | Farnell |  | LCSC
1 | U2008,U2007,U2006,U2005,U2004,U2003,U2002,U2001 | SOIC-14_3.9x8.7mm_P1.27mm | 8 | 74HC00-74xx
2 | U1806,U1707,U2107,U1102,U1414 | SOIC-14_3.9x8.7mm_P1.27mm | 5 | 74HC27 | 296-14848-1-ND‎ | £1.70 | 2777731 | £1.28 | C5629 | $0.68
3 | H4,H3,H2,H1 | MountingHole_3.2mm_M3 | 4 | Conn_01x01
4 | U313,U1802,U1517,U1508,U2108,U1416,U1503,U1504,U1703,U1801,U1903,U2103 | SOIC-14_3.9x8.7mm_P1.27mm | 12 | 74HC4075 | 296-9227-5-ND‎ | £4.78 | 2777741 | £5.78 | C6547 | tba
5 | U1506,U1803,U1805,U1522,U1521,U1520,U1519,U1902,U1701,U1408,U1407,U1502,U1601,U2105,U2106,U1507,U1510,U1511,U2104,U1403,U1405,U1406,U302,U303,U306,U1103,U1412,U1505,U1704 | SOIC-14_3.9x8.7mm_P1.27mm | 29 | 74HC08 | ‎MC74HC08ADGOS-ND‎ | £8.70 | 1201314 | £7.86 | C5593 | $2.64
6 | U1411,U1804,U1518,U1509,U1501,U1602,U1904,U1404,U307,U308,U310,U1413,U1516,U1702,U1901,U2102 | SOIC-14_3.9x8.7mm_P1.27mm | 16 | 74HC32 | MC74HC32ADGOS-ND‎ | £4.80 | 1607773 | £5.32 | C5632 | $1.83
7 | C1806,C1802,C1805,C1804,C1803,C1523,C1517,C1522,C1521,C1520,C1519,C1518,C1509,C1501,C1515,C1708,C2106,C2105,C2108,C2107,C1904,C1410,C1408,C1409,C1404,C1403,C1405,C1406,C1407,C201,C202,C203,C204,C205,C206,C207,C208,C209,C210,C211,C212,C213,C214,C301,C302,C303,C304,C305,C306,C307,C308,C309,C310,C311,C312,C313,C314,C315,C316,C317,C318,C319,C320,C321,C322,C323,C401,C402,C403,C501,C502,C503,C504,C505,C506,C507,C508,C601,C602,C603,C604,C605,C606,C607,C608,C609,C610,C611,C612,C613,C614,C701,C702,C801,C802,C901,C1001,C1002,C1003,C1004,C1101,C1102,C1103,C1201,C1202,C1203,C1204,C1205,C1206,C1207,C1301,C1401,C1402,C1411,C1412,C1413,C1414,C1415,C1416,C1417,C1418,C1419,C1502,C1503,C1504,C1505,C1506,C1507,C1508,C1510,C1511,C1512,C1513,C1514,C1516,C1601,C1602,C1603,C1604,C1605,C1701,C1702,C1703,C1704,C1705,C1706,C1707,C1801,C1901,C1902,C1903,C2101,C2102,C2103,C2104 | C_0603_1608Metric | 155 | 100n | 1276-1000-1-ND | £1.50 | 1856360 | £2.42 | C159815 | $0.16
8 | U1515,U309,U1204,U1205,U1206,U1301,U1417,U1418,U1419,U1514,U1513 | SOIC-16_3.9x9.9mm_P1.27mm | 11 | 74HC238 | MC74HC238ADGOS-ND‎ | £3.19 | 2534432 | £3.80 | C5620 | $1.32
9 | U1202,U1201,U1203,U1207 | SOIC-14_3.9x8.7mm_P1.27mm | 4 | 74HC11 | MC74HC11ADGOS-ND | £1.16 | 1236212 | £1.54 | C88001 | $0.59
10 | U1706,U1401 | SOIC-14_3.9x8.7mm_P1.27mm | 2 | 74HC00 | 1727-3774-ND | £0.56 | 1201310 | £1.26 | C336025 | $0.36
11 | U1603,U1409,U311,U1001 | SOIC-14_3.9x8.7mm_P1.27mm | 4 | 74HC04 | MC74HC04ADGOS-ND | £1.12 | 2854595 | £0.77 | C86613 | $0.36
12 | U208,U214,U201,U202,U203,U204,U205,U206,U207,U209,U210,U211,U212,U213,U305,U505,U507,U605,U606,U612,U613 | SOIC-20W_7.5x12.8mm_P1.27mm | 21 | 74HC574 | 1727-2819-1-ND | £6.66 | 1085345 | £8.62 | C16501 | $2.70
13 | U1002,U304,U312,U315,U316,U321,U322,U323,U403,U502,U504,U601,U602,U603,U604,U611,U614,U701,U702,U1003,U1004 | SOIC-20W_7.5x12.8mm_P1.27mm | 21 | 74HC541 | MC74HC541ADWR2GOSCT-ND | £7.81 | 1201325 | £9.65 | C9367 | $6.30
14 | U301 | SOIC-16_3.9x9.9mm_P1.27mm | 1 | 74HC138 | MC74HC138ADGOS-ND | £0.29 | 1104715 | £1.23 | C5602 | $0.45
15 | U314,U317,U801 | SOIC-14_3.9x8.7mm_P1.27mm | 3 | 74HC86 | MC74HC86ADGOS-ND‎ | £0.84 | 1085331 | £1.31 | C5955 | $0.46
16 | U318 | SOIC-14_3.9x8.7mm_P1.27mm | 1 | 74HC4002 | 296-31584-1-ND | £0.48 | 1739942 | £0.45 | n/a
17 | U319,U320,U607,U608,U609,U610 | SOIC-16_3.9x9.9mm_P1.27mm | 6 | 74HC283 | 296-31579-1-ND‎ | £2.82 | 1740249 | £3.02 | C139343 | $4.35
18 | U401,U1101 | SOIC-14_3.9x8.7mm_P1.27mm | 2 | 74HC74 | MC74HC74ADGOS-ND | £0.56 | 1201317 | £1.30 | C27597 | $0.43
19 | U402,U802,U1604,U1605 | SOIC-16_3.9x9.9mm_P1.27mm | 4 | 74HC157 | 296-14836-1-ND | £1.48 | 2534421 | £1.25 | C233460 | $0.62
20 | U501,U503,U506,U508,U901 | SOIC-16_3.9x9.9mm_P1.27mm | 5 | 74HC163 | 296-8245-5-ND | £1.55 | 1739778 | £2.81 | C338758 | $1.00
21 | U1402,U1523,U1705 | SOIC-14_3.9x8.7mm_P1.27mm | 3 | 74HC02 | MC74HC02ADGOS-ND | £0.93 | 2445101 | £1.20 | C7328 | $0.43
22 | U1708 | SOIC-14_3.9x8.7mm_P1.27mm | 1 | 74HC10 | 296-8213-5-ND | £0.32 | 1085336 | £1.50 | C6816 | $0.14
23 | J2001 | PinHeader_2x20_P2.54mm_Vertical_SMD | 1 | Conn_02x20_Odd_Even | ‎609-3124-ND‎ | £1.00 | 2751390 | £0.94 | n/a
 |  |  |  | Total |  | £52.25 |  | £63.31 |  | $24.83
 |  |  |  | inc VAT |  | £62.70 |  | £75.97 |  | £29.79

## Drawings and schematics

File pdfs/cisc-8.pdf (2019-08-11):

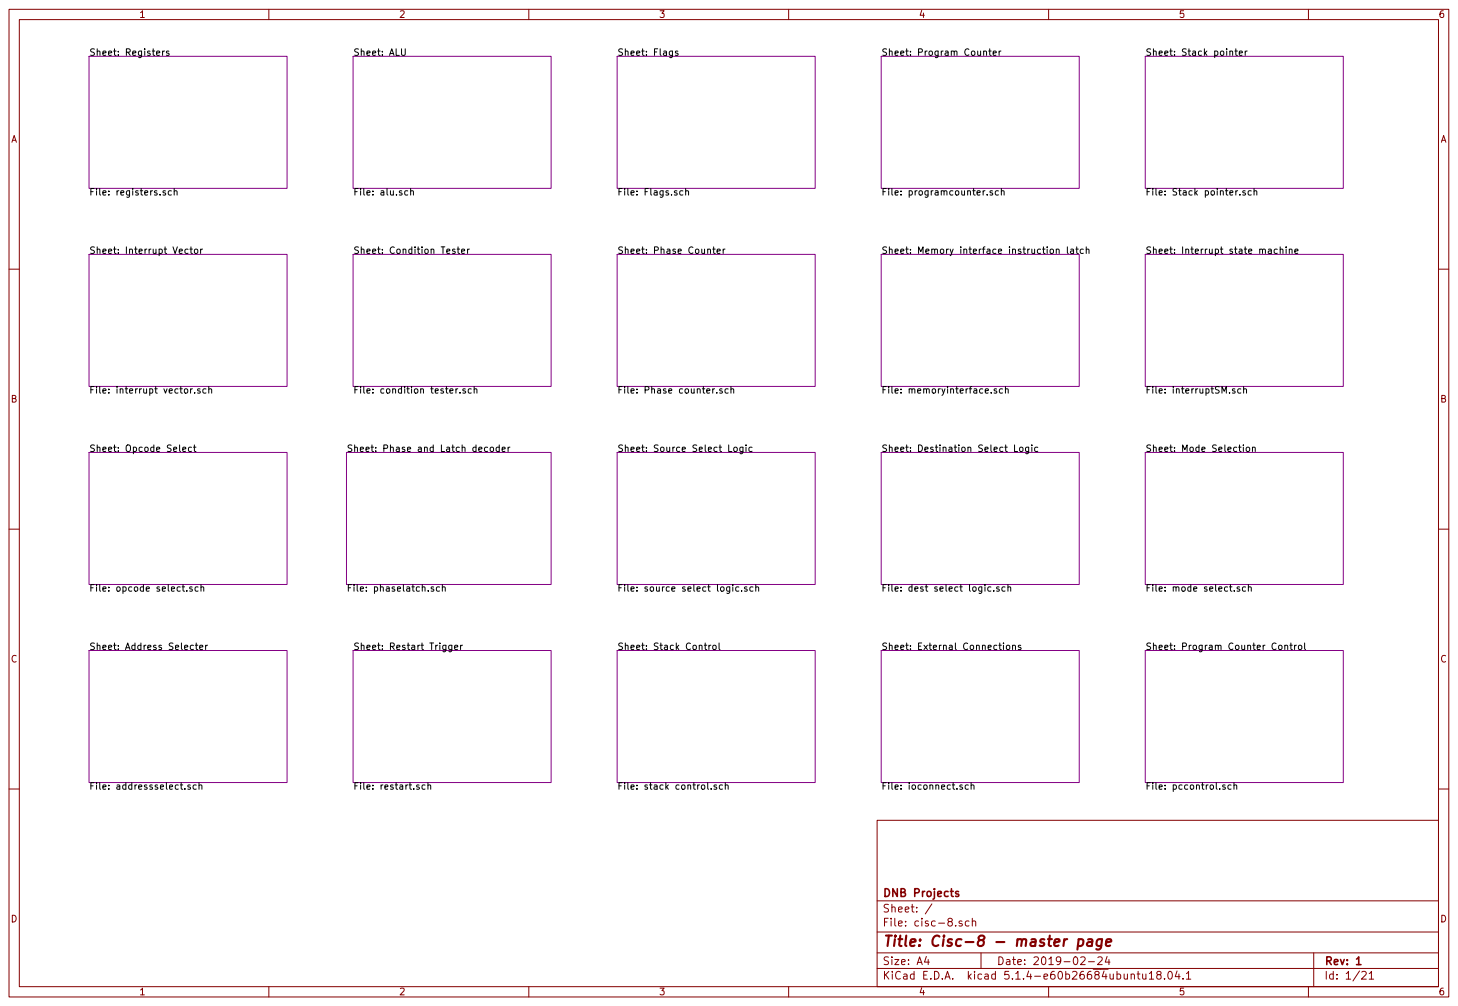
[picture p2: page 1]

File: Flags.sch Sheet: ALU

File: Stack pointer.sch

File: memoryinterface.sch Sheet: Phase Counter File: Phase counter.sch Sheet: Condition Tester File: condition tester.sch Sheet: Interrupt Vector

Sheet: Memory interface instruction latch

Sheet: Interrupt state machine

File: interrupt vector.sch

Sheet: Phase and Latch decoder File: phaselatch.sch

Sheet: Source Select Logic

File: opcode select.sch

File: source select logic.sch

File: dest select logic.sch

Sheet: Program Counter Control

File: cisc-8.sch Sheet: / DNB Projects

Id: 1/21 Title: Cisc-8 - master page

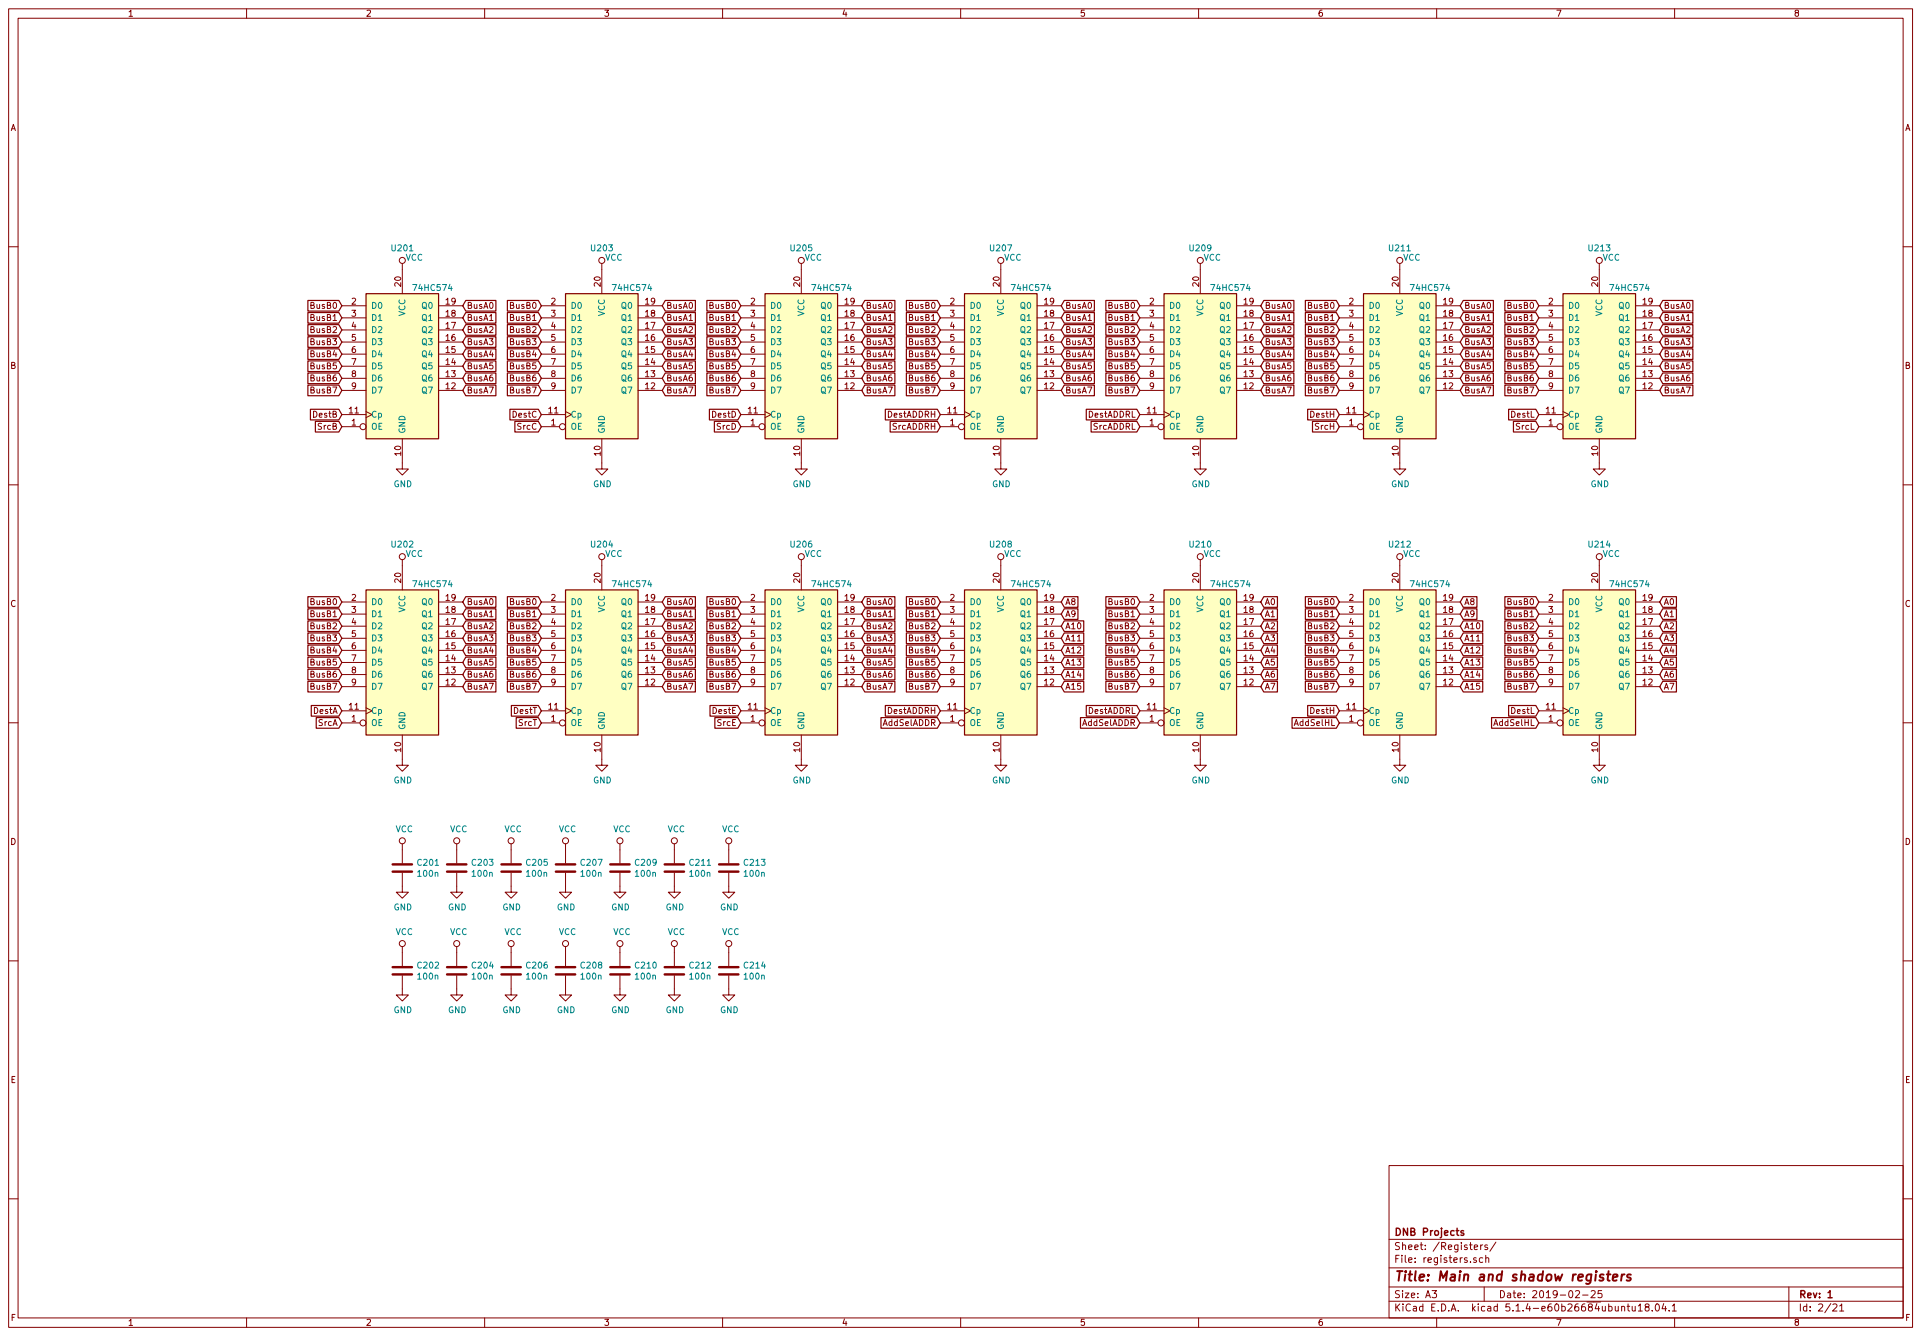
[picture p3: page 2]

DNB Projects
Sheet: /Registers/
File: registers.sch
Id: 2/21 Title: Main and shadow registers

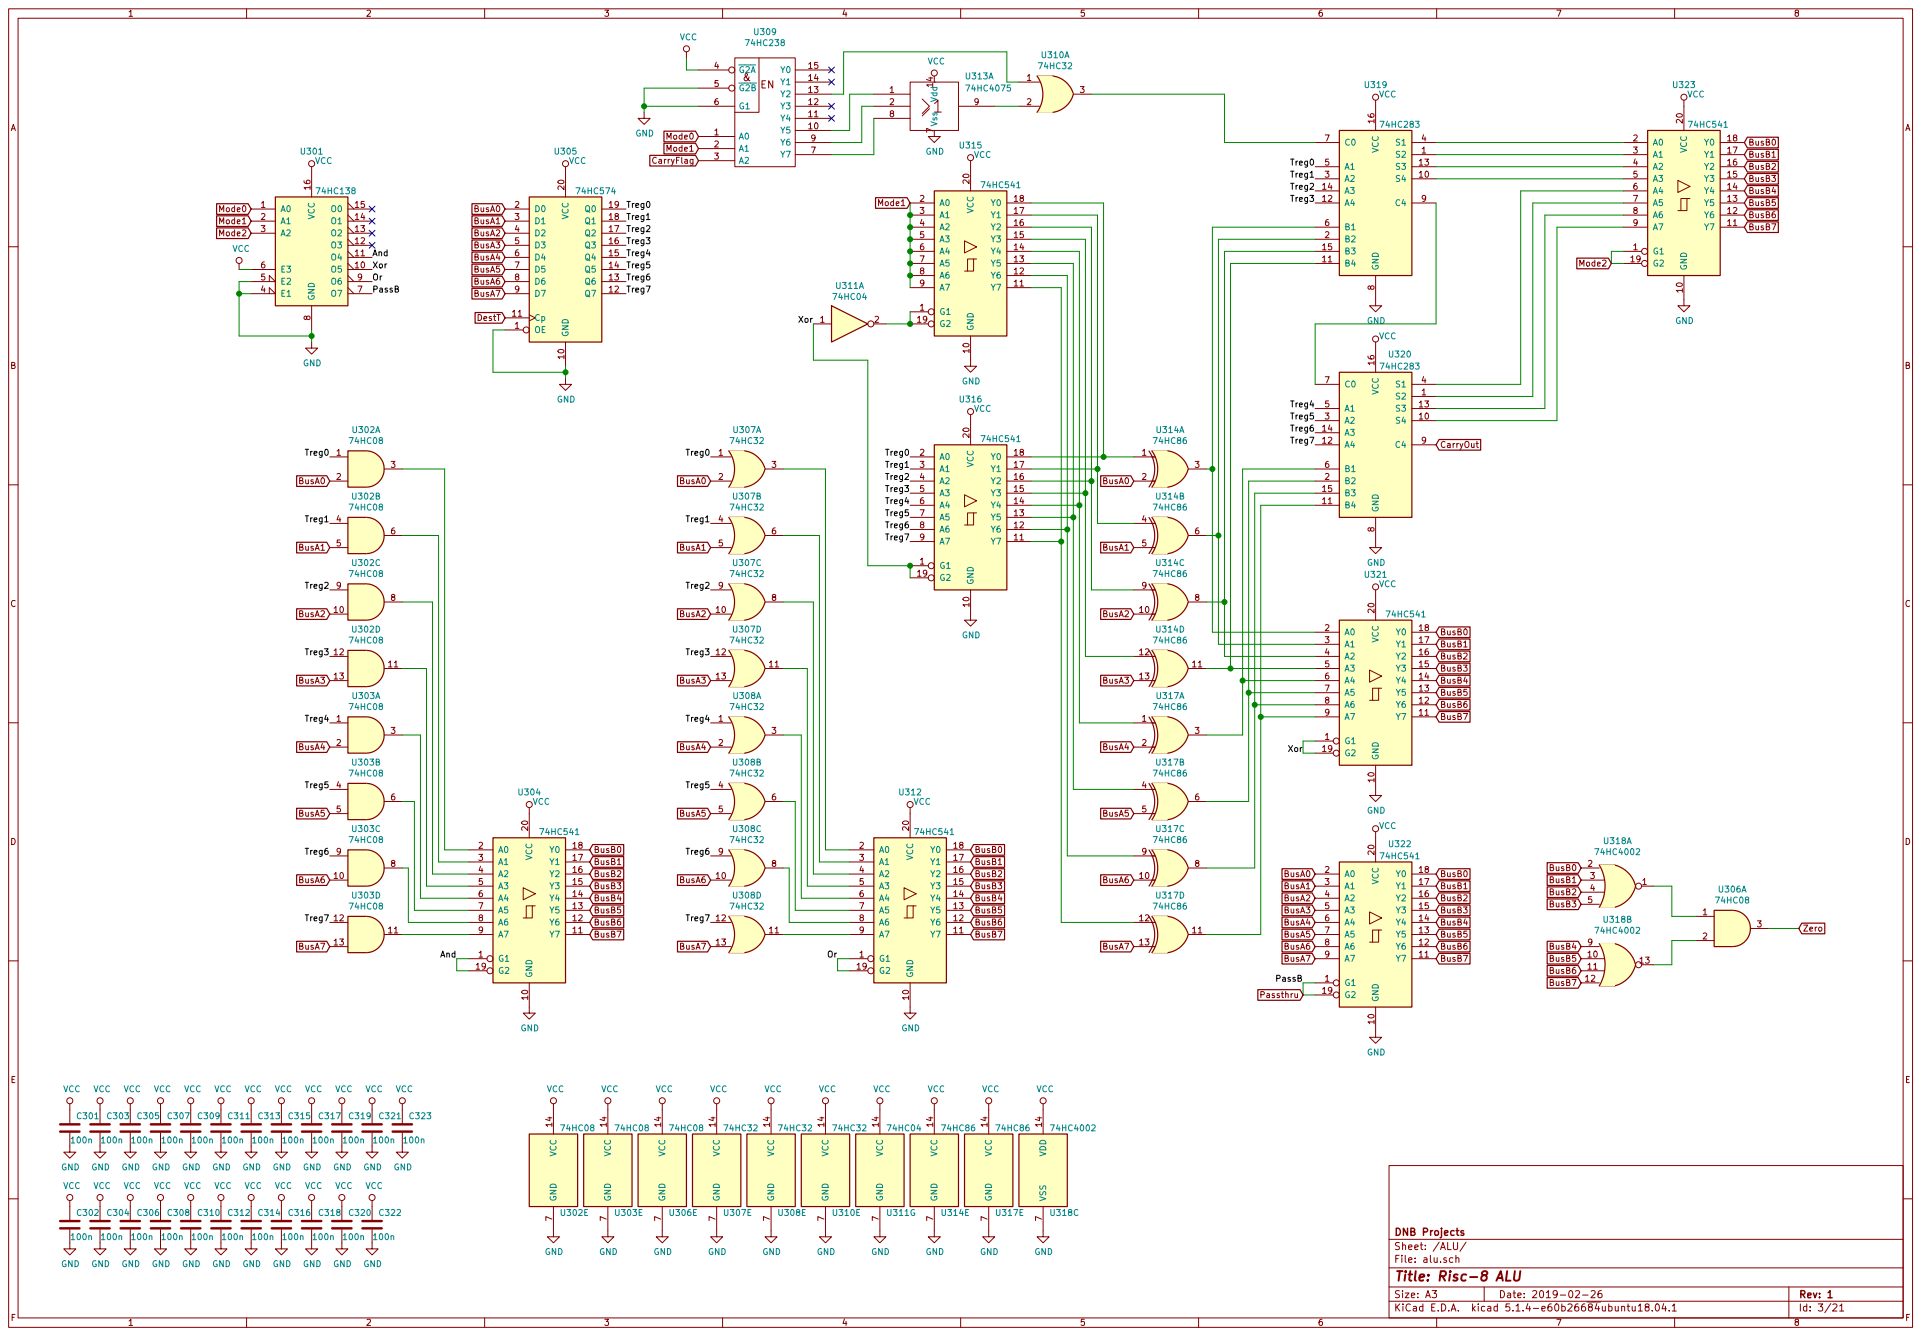
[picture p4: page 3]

74HC04 VCC GND VCC 14 GND

File: alu.sch Sheet: /ALU/ DNB Projects C303

Id: 3/21 Title: Risc-8 ALU

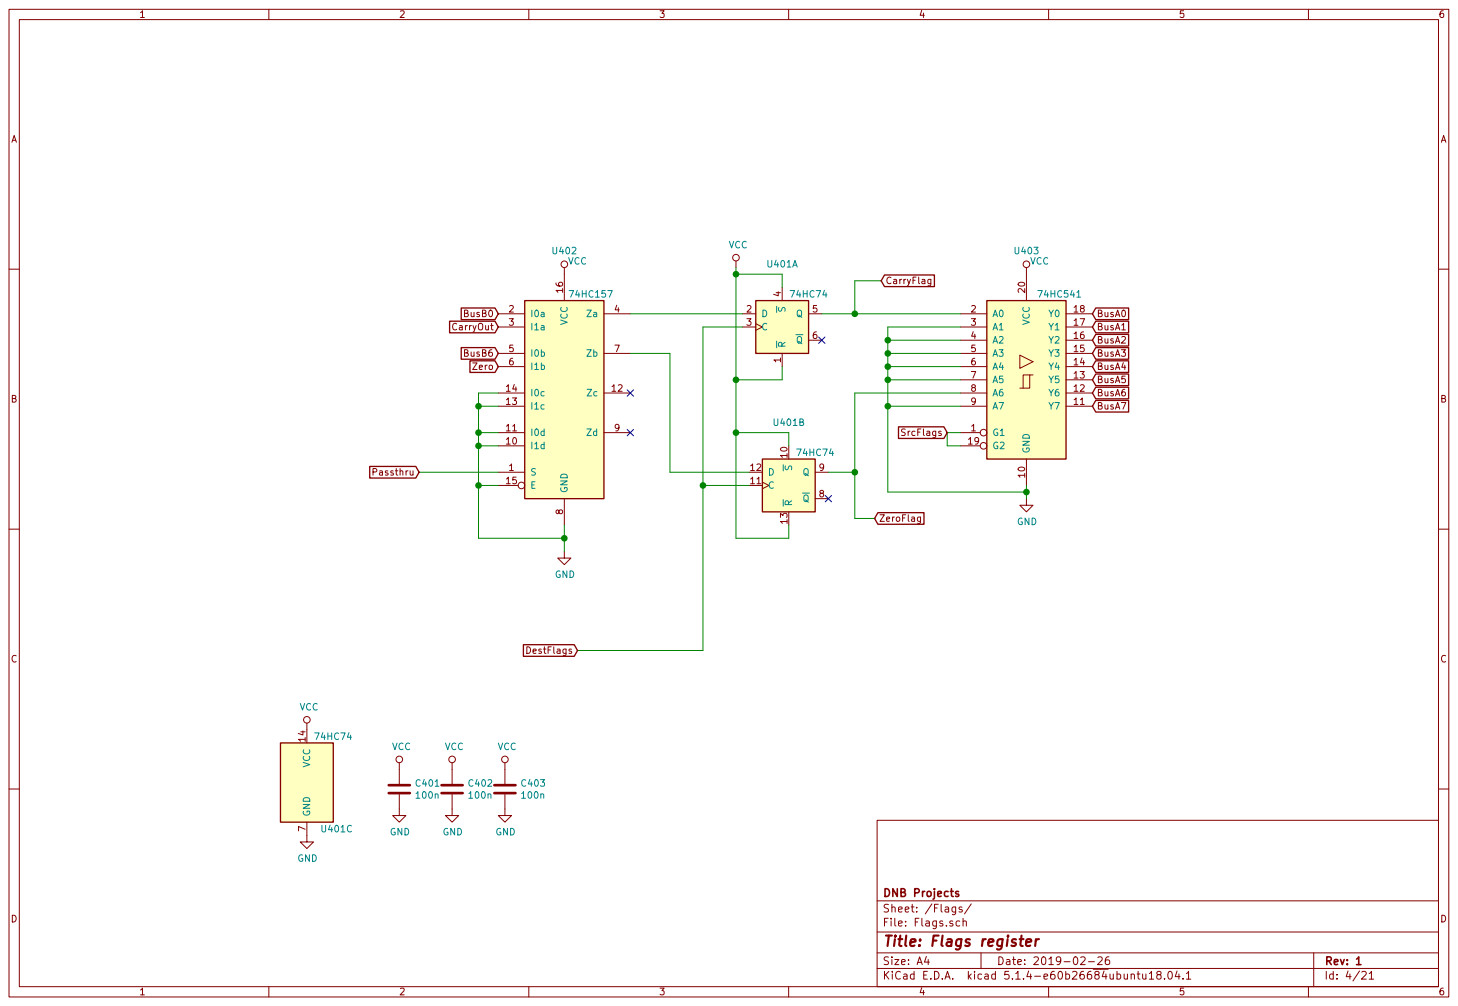
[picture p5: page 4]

DNB Projects
Sheet: /Flags/
File: Flags.sch
Id: 4/21 Title: Flags register

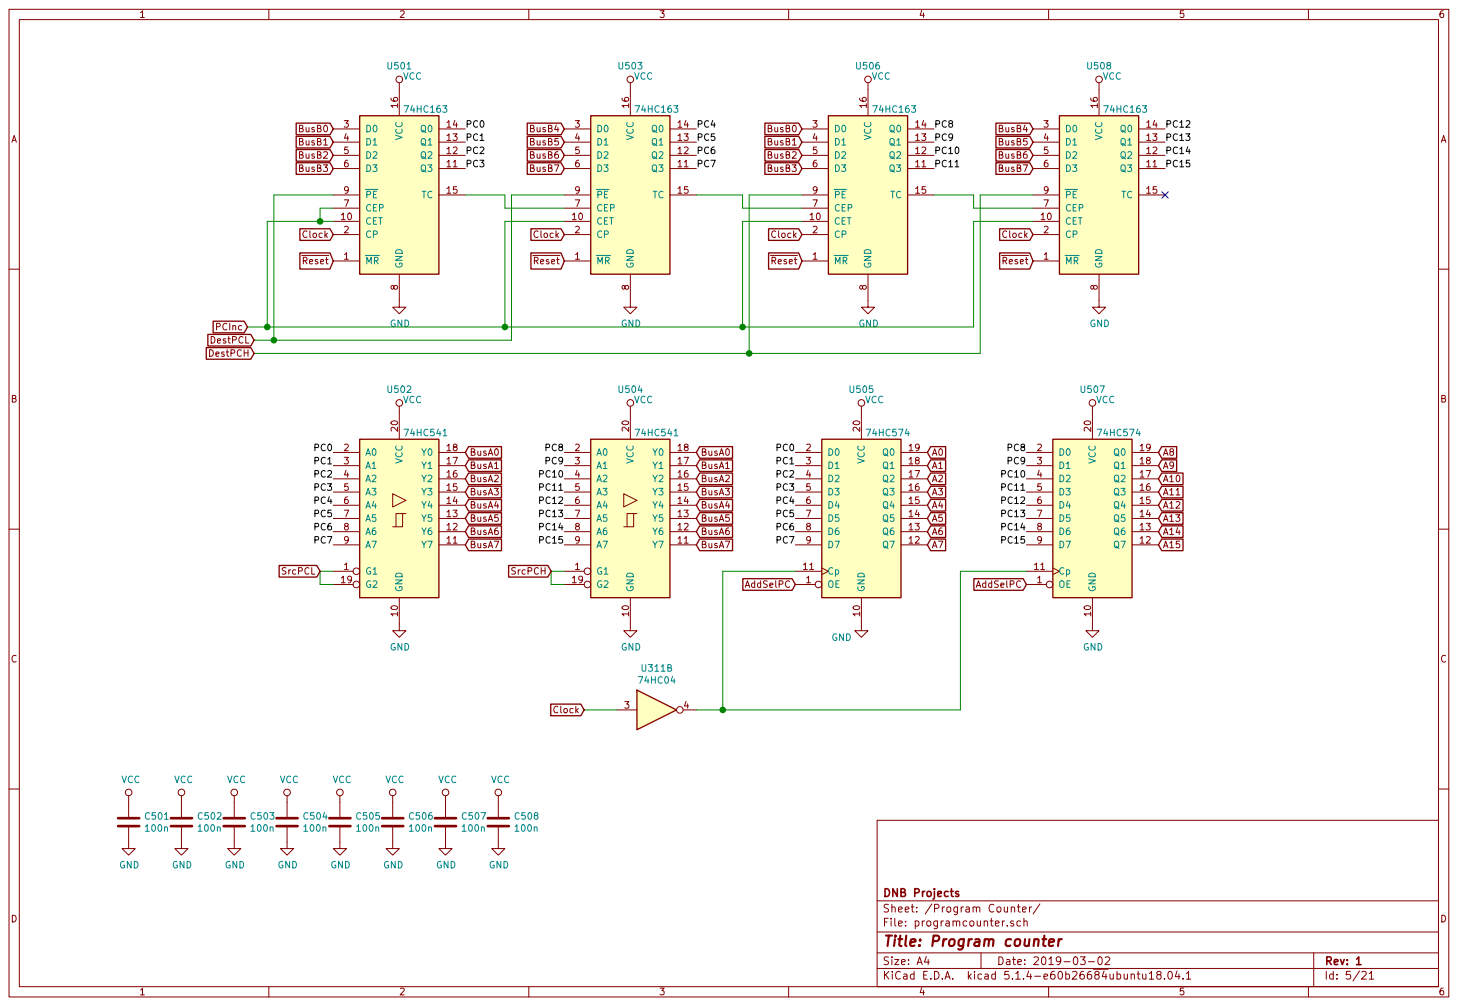
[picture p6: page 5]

Sheet: /Program Counter/
File: programcounter.sch
Id: 5/21 Title: Program counter

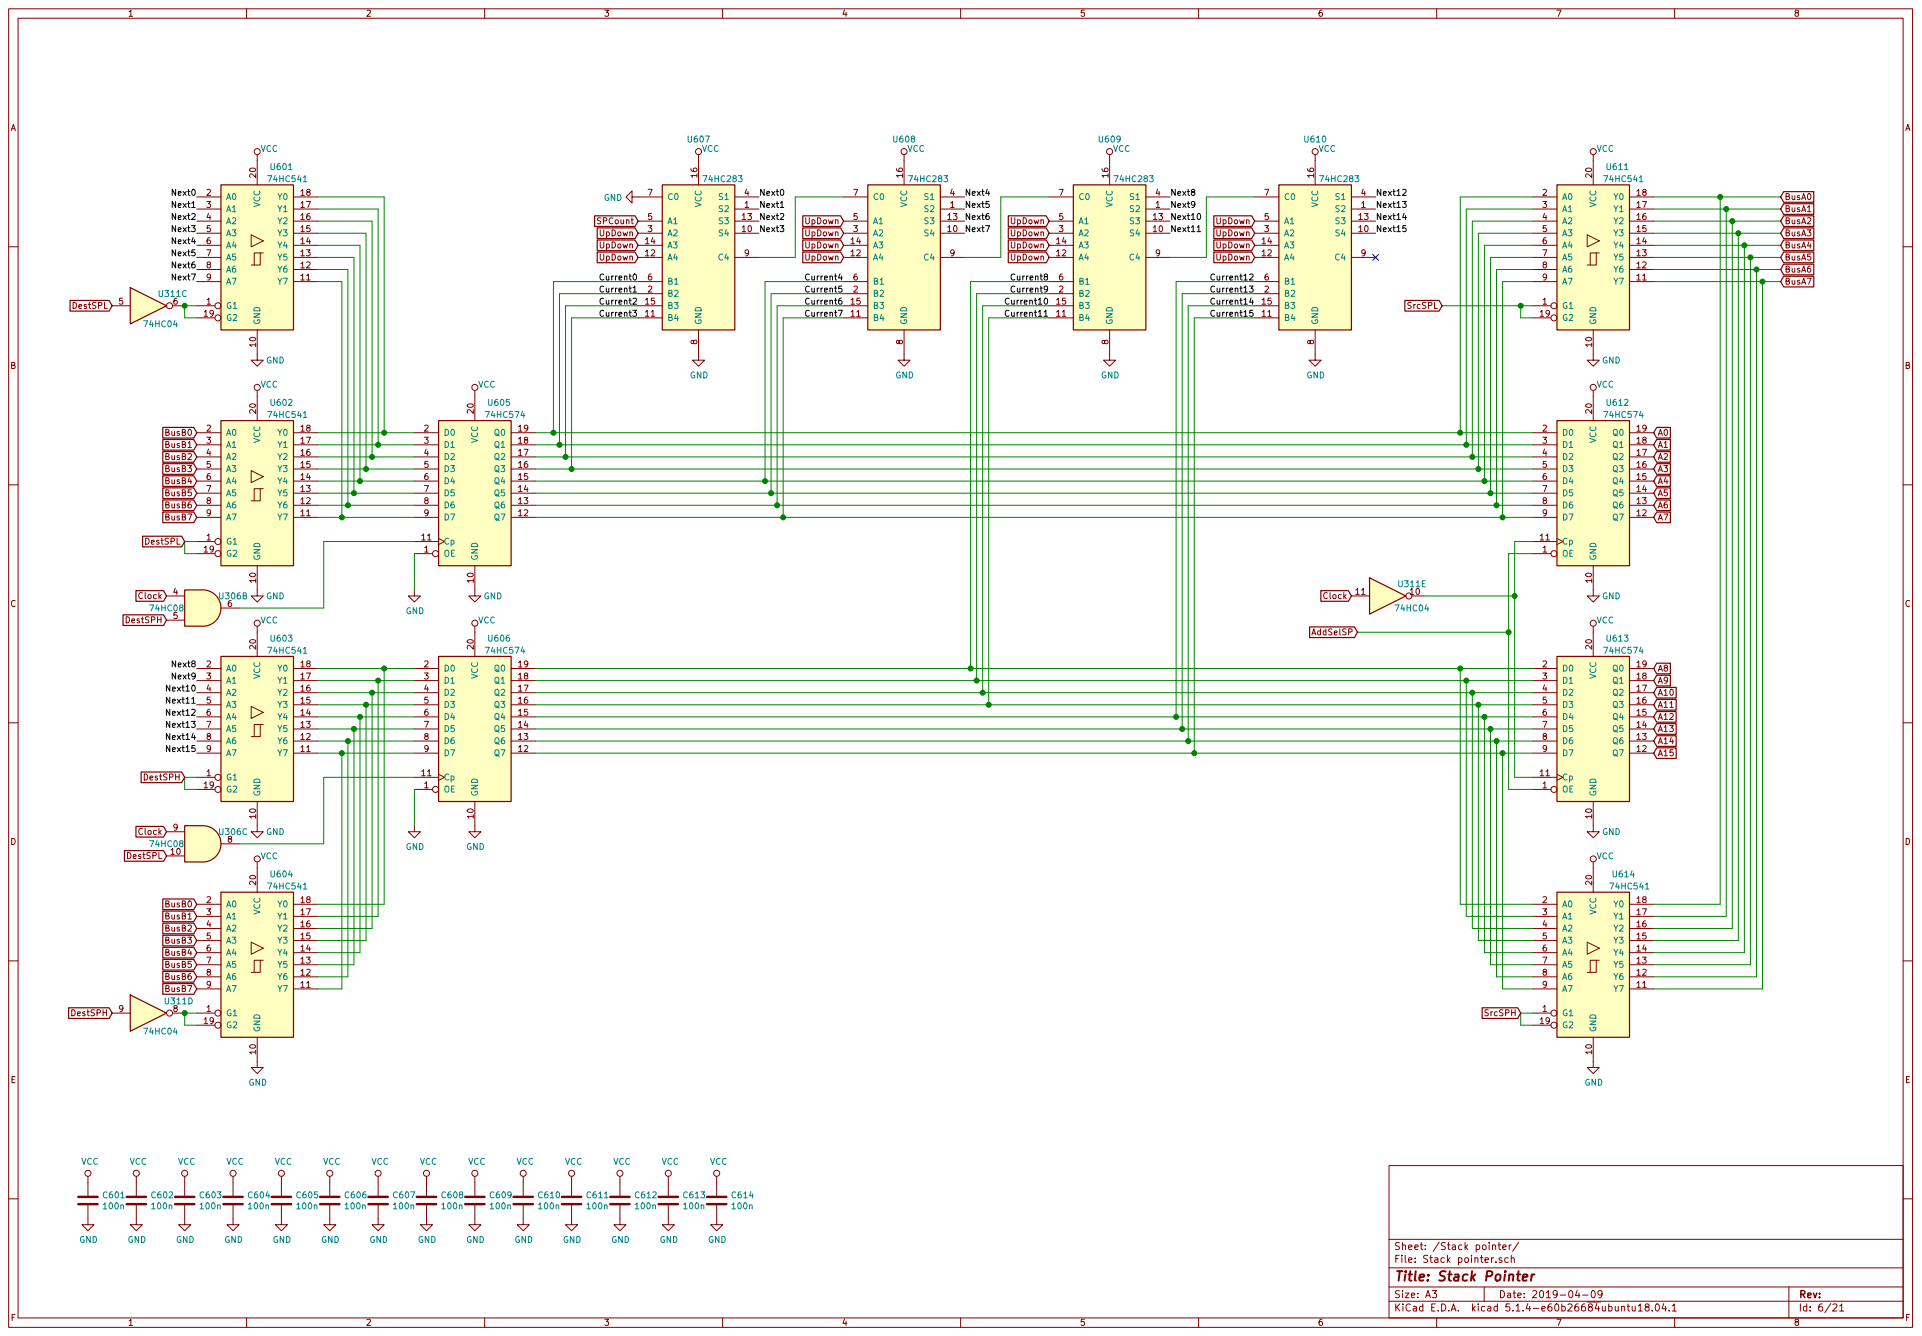
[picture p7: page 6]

Sheet: /Stack pointer/
File: Stack pointer.sch
Id: 6/21 Title: Stack Pointer

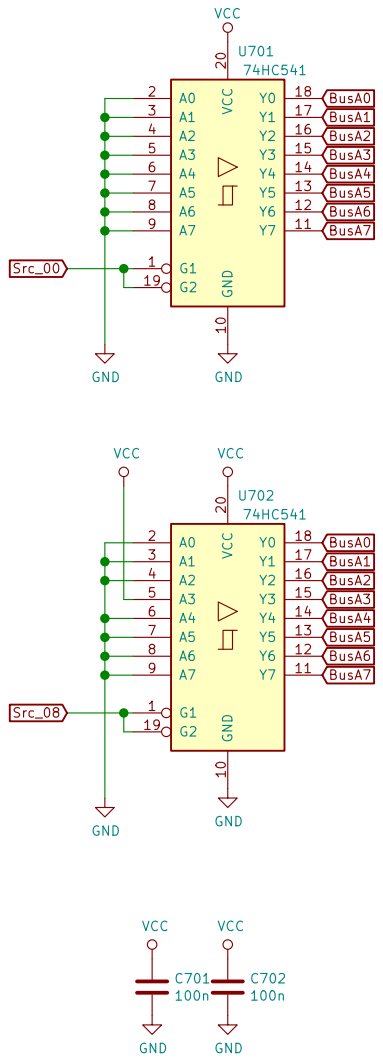
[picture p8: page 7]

File: interrupt vector.sch
Id: 7/21 Title: Interrupt Vector

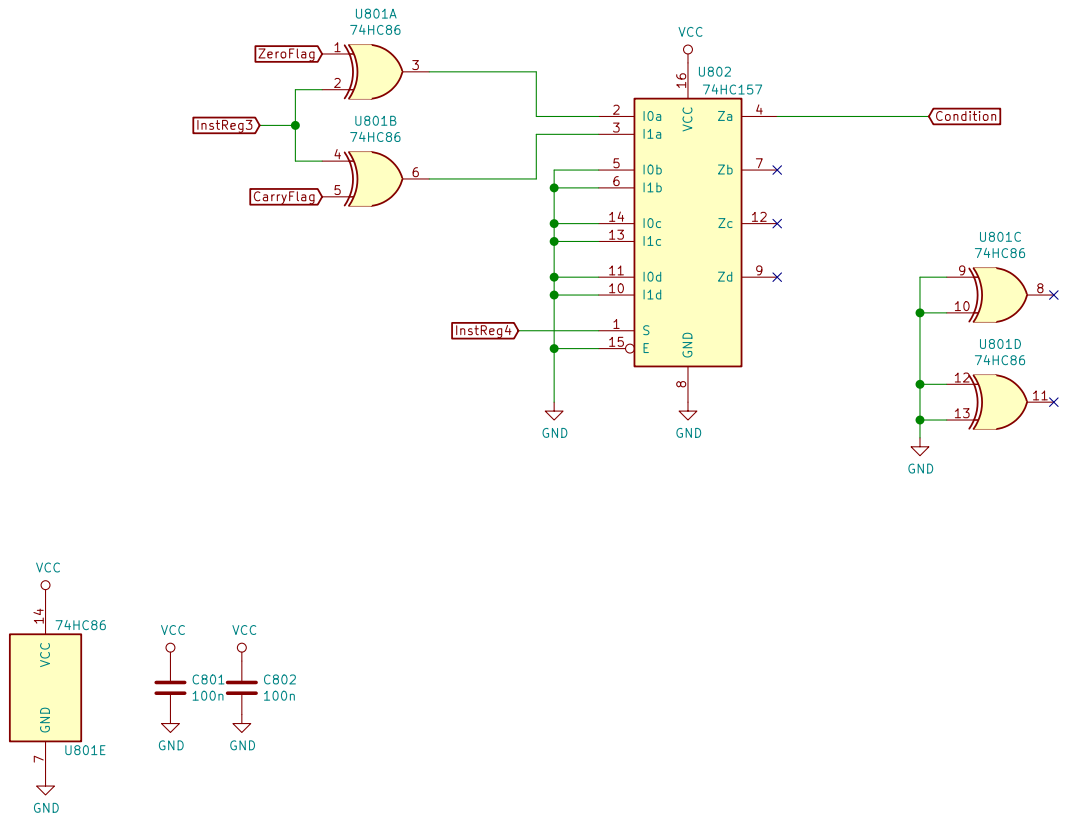
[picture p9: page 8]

Id: 8/21 Title: Condition Tester File: condition tester.sch Sheet: /Condition Tester/ GND

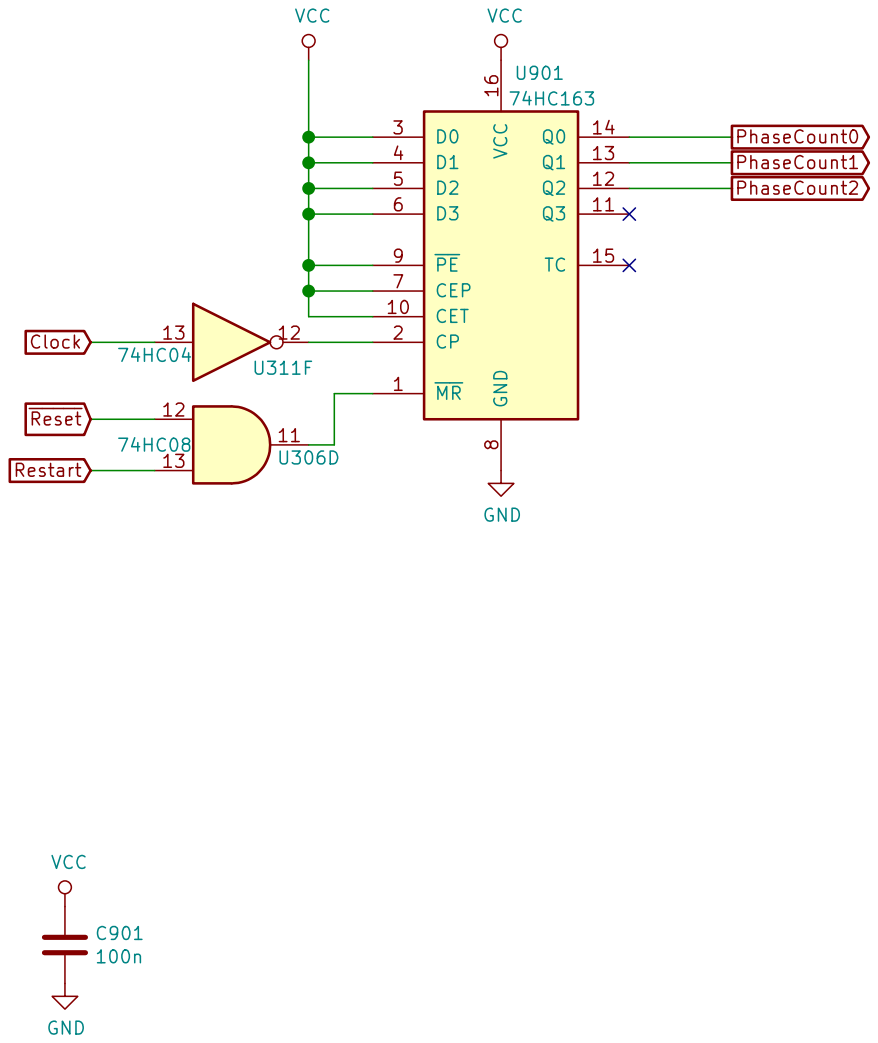
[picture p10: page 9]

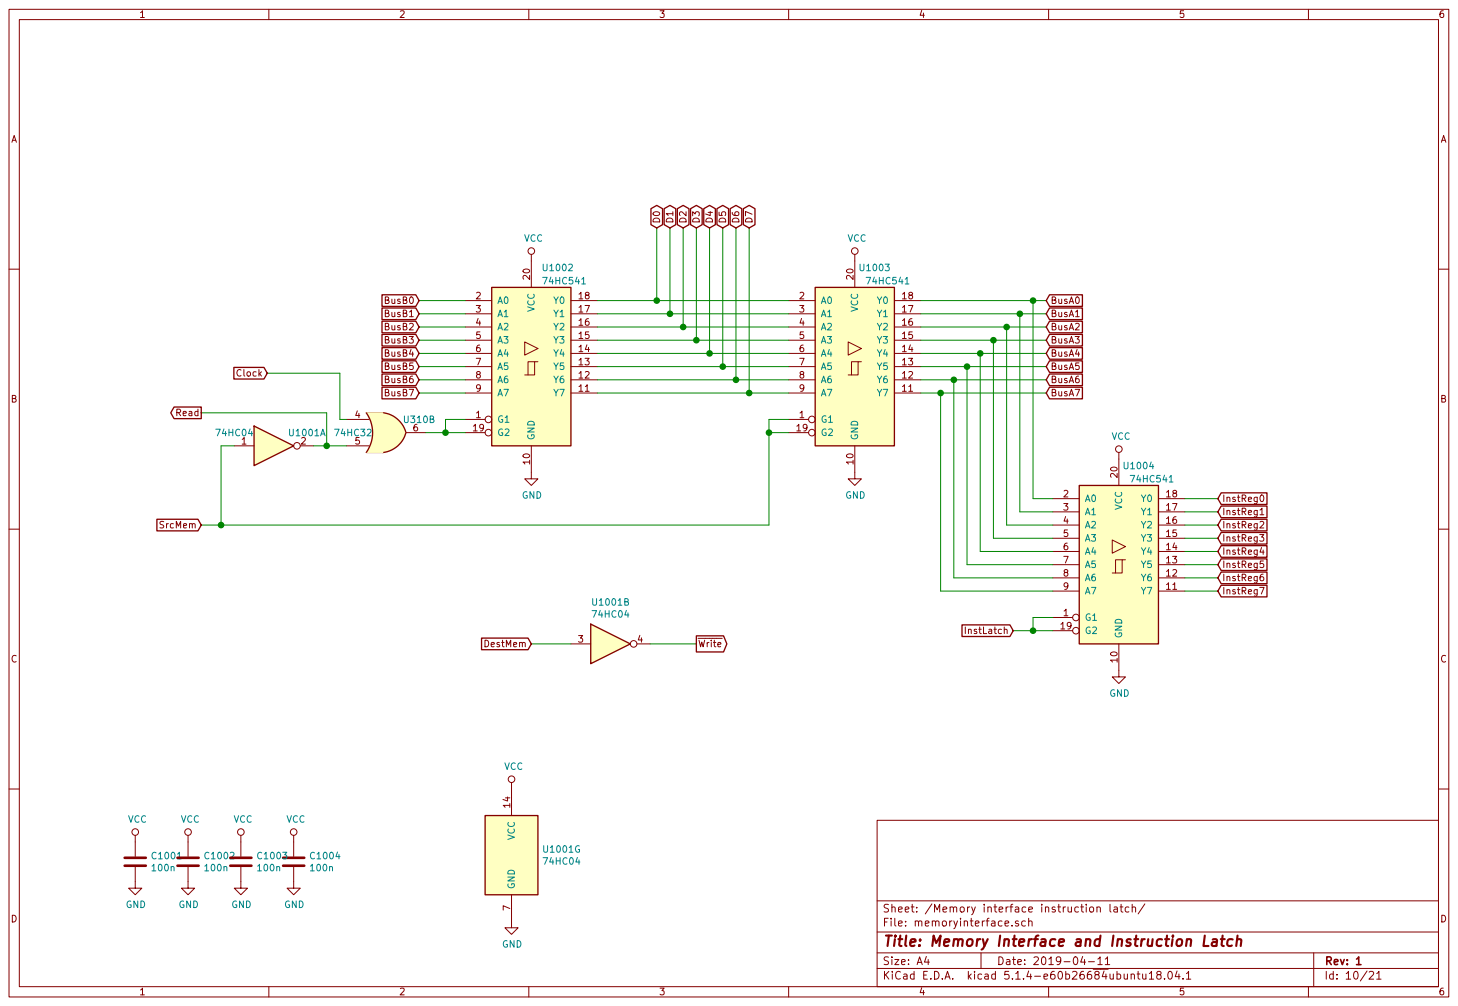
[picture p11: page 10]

File: memoryinterface.sch
Id: 10/21 Title: Memory Interface and Instruction Latch

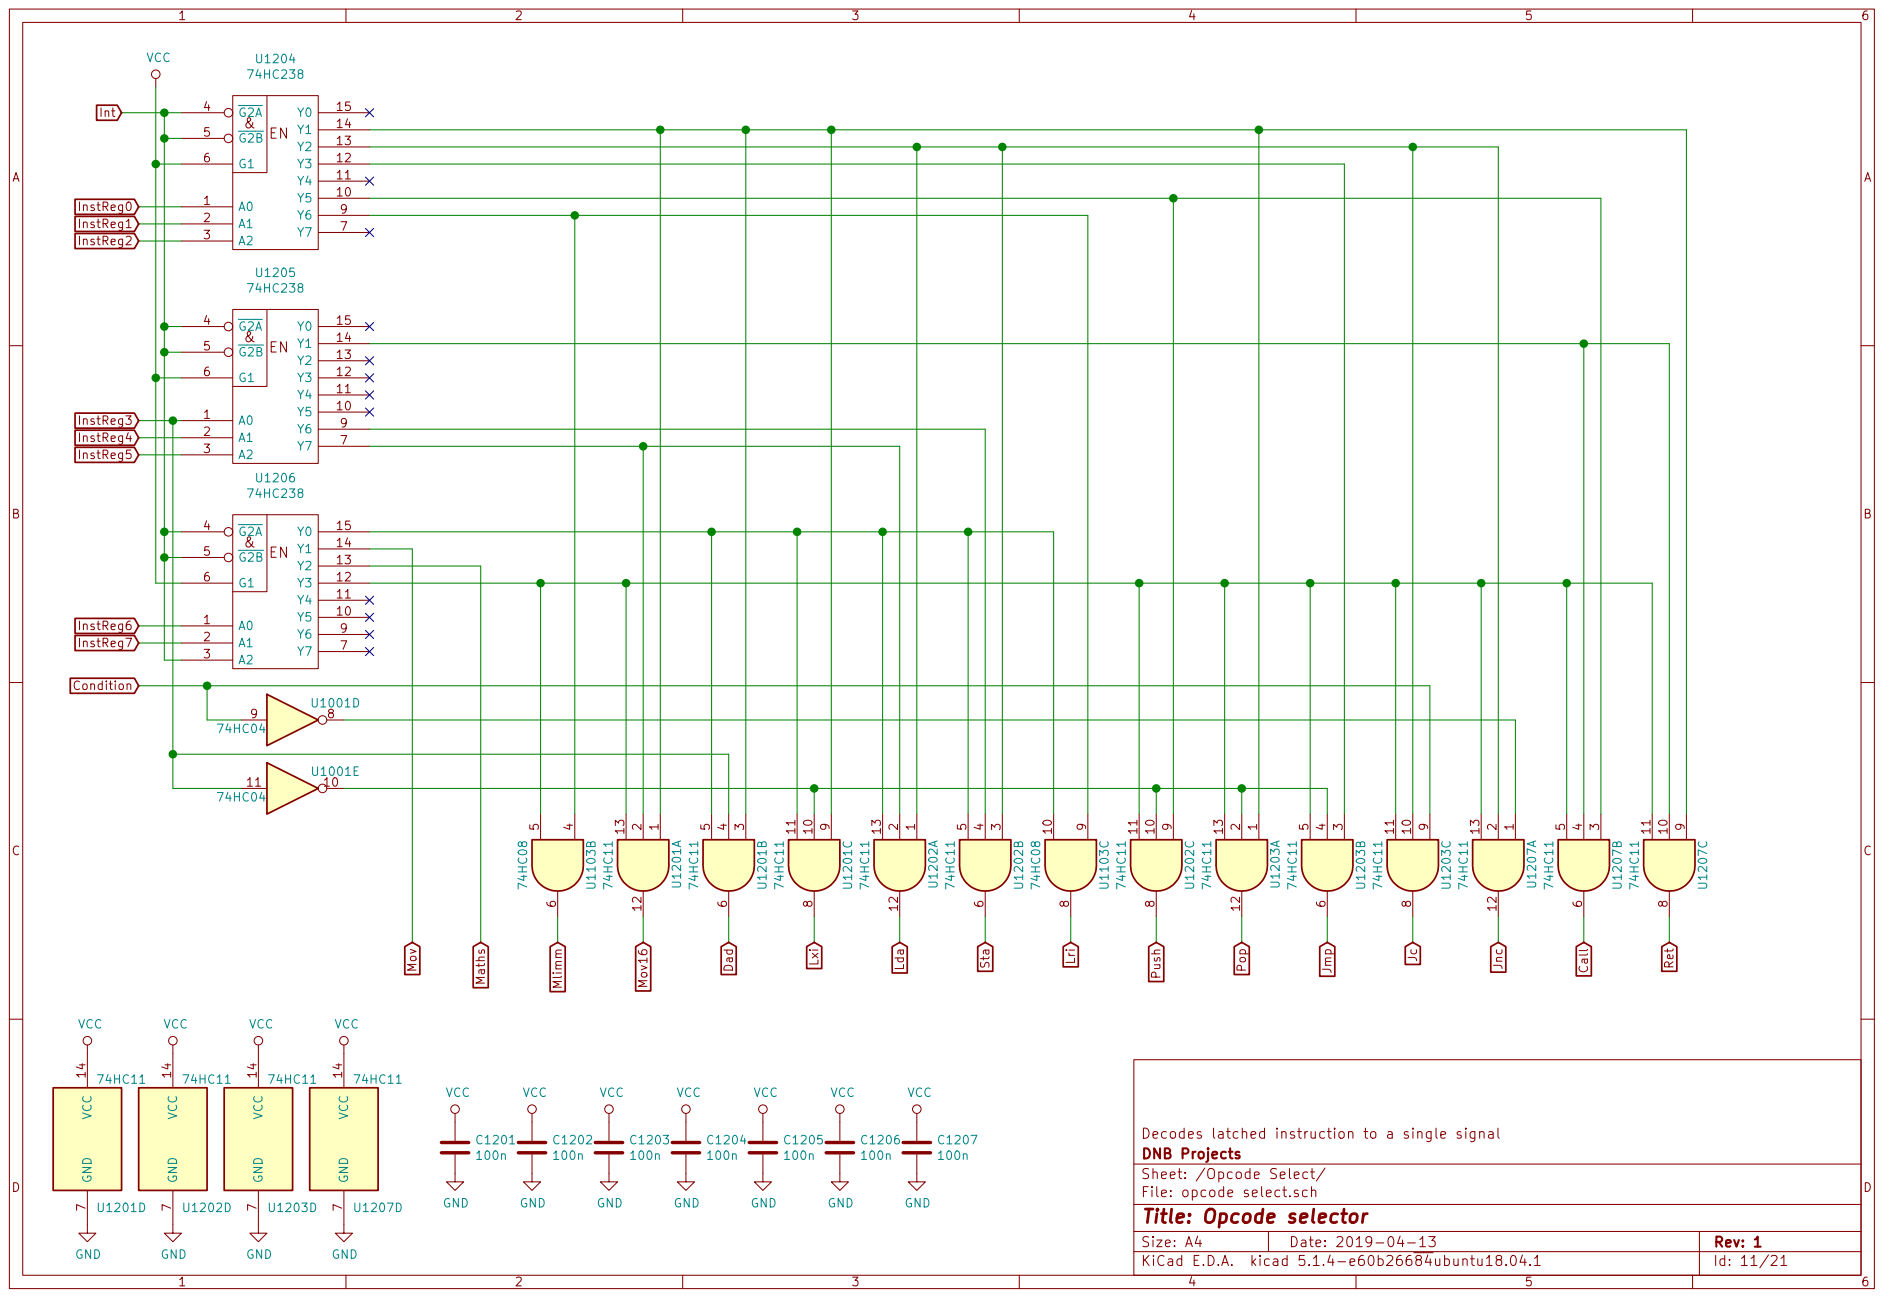
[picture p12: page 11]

DNB Projects
Sheet: /Opcode Select/
File: opcode select.sch
Id: 11/21 Title: Opcode selector

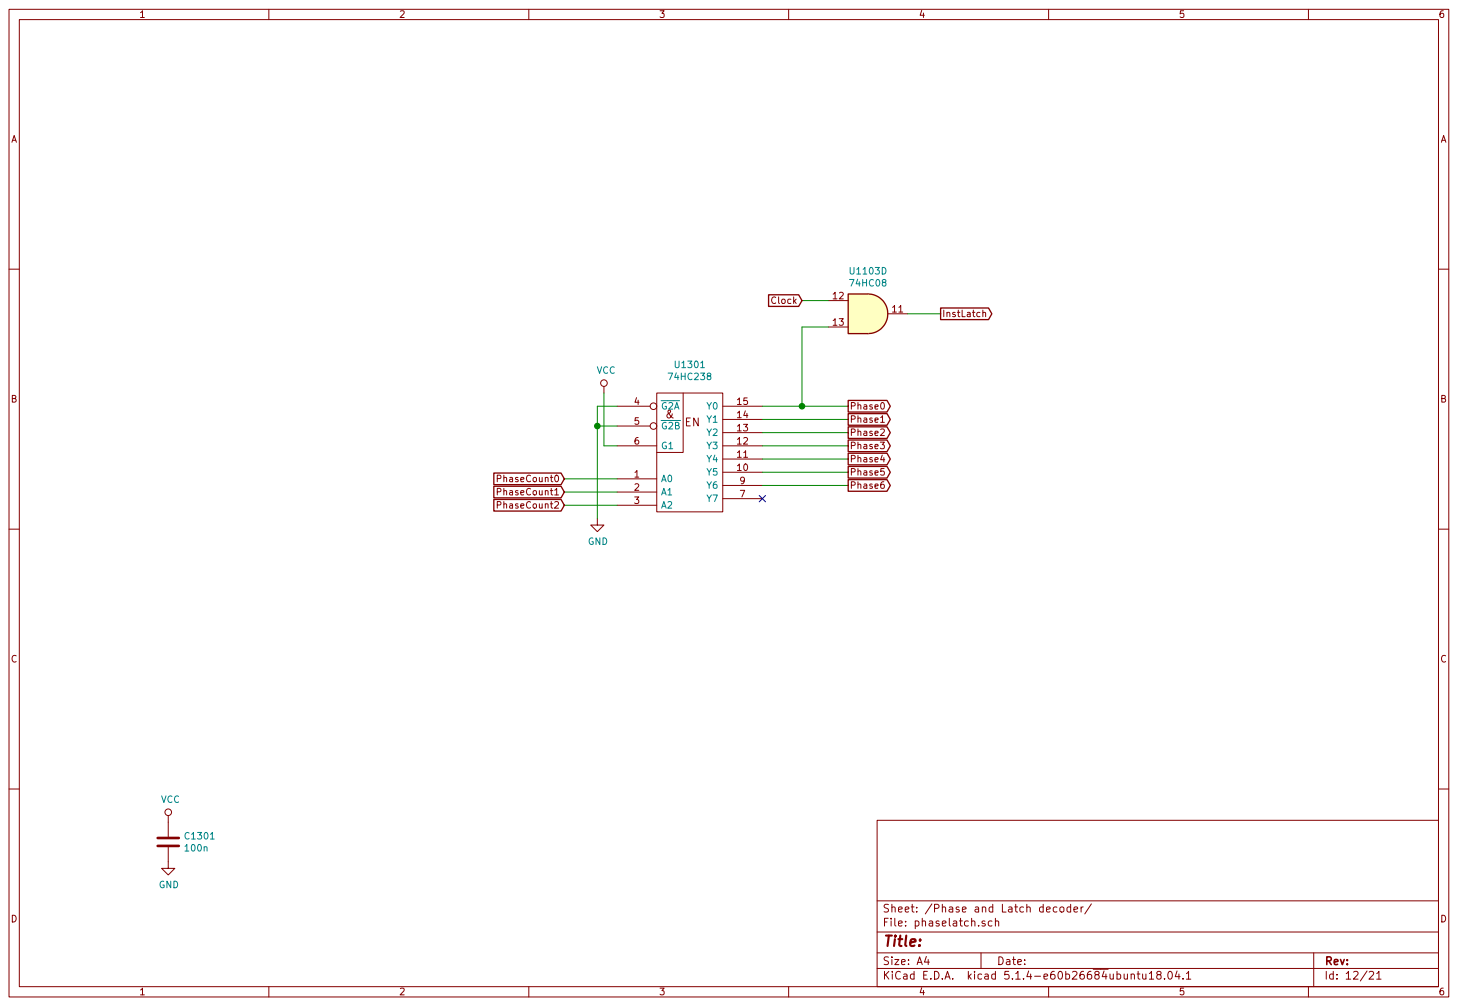
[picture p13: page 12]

File: phaselatch.sch Sheet: /Phase and Latch decoder/ &


Phase1 Dad Mov16 Phase2 Phase1 Mov Maths Phase2 Mlimm

Selects the source register (or memory) for every instruction GND GND

DNB Projects
Sheet: /Source Select Logic/
File: source select logic.sch
Id: 13/21 Title: Source Select Logic


Maths Phase1 Phase1
Lri Mov16 Phase3 Pop Phase2 Maths Mlimm

Selects the destination for each instruction phase GND

DNB Projects
Sheet: /Destination Select Logic/
File: dest select logic.sch
Id: 14/21 Title: Destination Select Logic


VCC
Selects or overrides the arithmetic/logical control bits C1603

File: mode select.sch Sheet: /Mode Selection/ DNB Projects

Id: 15/21 Title: Mode Selection


Call Phase4 Phase3 Ret Call Phase2 Ret Pop Push Phase1 Phase0 Pop

100n VCC GND VCC 14 GND
74HC00 GND

Selects prog counter, stack pointer, HL, or ADDR to memory C1705

File: addressselect.sch Sheet: /Address Selecter/ DNB Projects

Id: 16/21 Title: Address Source Selection


Lxi Lda Phase2 Call Phase6 Dad Phase4 Maths Phase3 Mlimm

Detects the end of each instruction and restarts the phase counter C1803
100n GND

DNB Projects
Id: 17/21 Title: Restart trigger File: restart.sch Sheet: /Restart Trigger/


Controls when and in which direction the stack pointer moves VCC

Id: 18/21 Title: Stack Control File: stack control.sch Sheet: /Stack Control/ DNB Projects


File: ioconnect.sch Sheet: /External Connections/ Dummy components are DNF to provide spare footprints

Id: 19/21 Title: External connections and dummy footprints


Controls access to and timing for Program Counter VCC

DNB Projects
Sheet: /Program Counter Control/
File: pccontrol.sch
Id: 20/21 Title: Program Counter Control


File: interruptSM.sch
Id: 21/21 Title: Interrupt Control State Machine

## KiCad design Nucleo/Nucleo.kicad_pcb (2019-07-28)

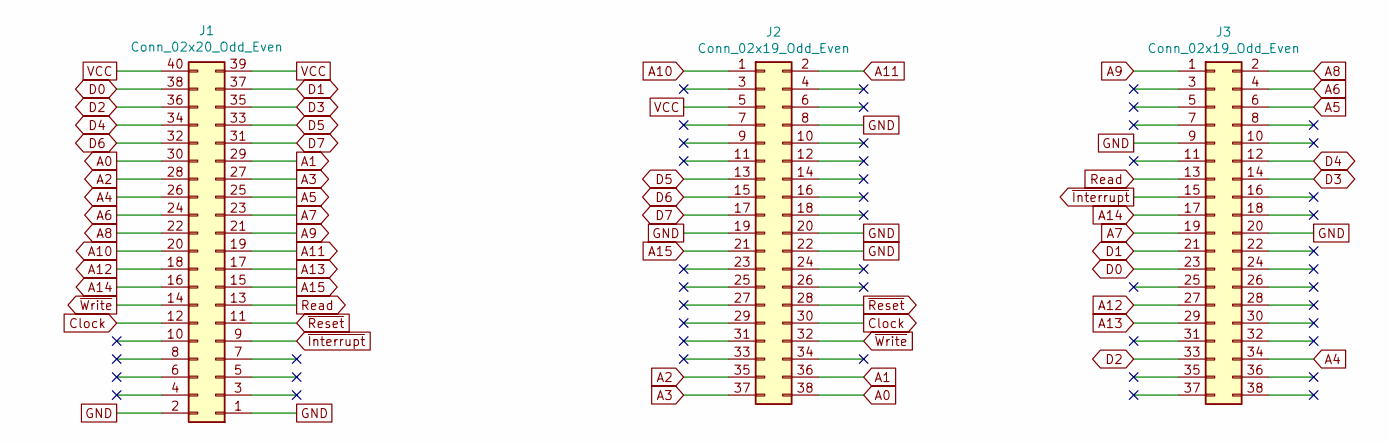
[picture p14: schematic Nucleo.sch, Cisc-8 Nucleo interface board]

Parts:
J1: Conn_02x20_Odd_Even; PinHeader_2x20_P2.54mm_Vertical_SMD
J2, J3: Conn_02x19_Odd_Even; PinHeader_2x19_P2.54mm_Vertical

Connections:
A0: J1.30, J2.38
A1: J1.29, J2.36
A2: J1.28, J2.35
A3: J1.27, J2.37
A4: J1.26, J3.34
A5: J1.25, J3.6
A6: J1.24, J3.4
A7: J1.23, J3.19
A8: J1.22, J3.2
A9: J1.21, J3.1
A10: J1.20, J2.1
A11: J1.19, J2.2
A12: J1.18, J3.27
A13: J1.17, J3.29
A14: J1.16, J3.17
A15: J1.15, J2.21
Clock: J1.12, J2.30
D0: J1.38, J3.23
D1: J1.37, J3.21
D2: J1.36, J3.33
D3: J1.35, J3.14
D4: J1.34, J3.12
D5: J1.33, J2.13
D6: J1.32, J2.15
D7: J1.31, J2.17
GND: J1.1, J1.2, J2.8, J2.19, J2.20, J2.22, J3.9, J3.20
Read: J1.13, J3.13
VCC: J1.39, J1.40, J2.5
~Interrupt: J1.9, J3.15
~Reset: J1.11, J2.28
~Write: J1.14, J2.32

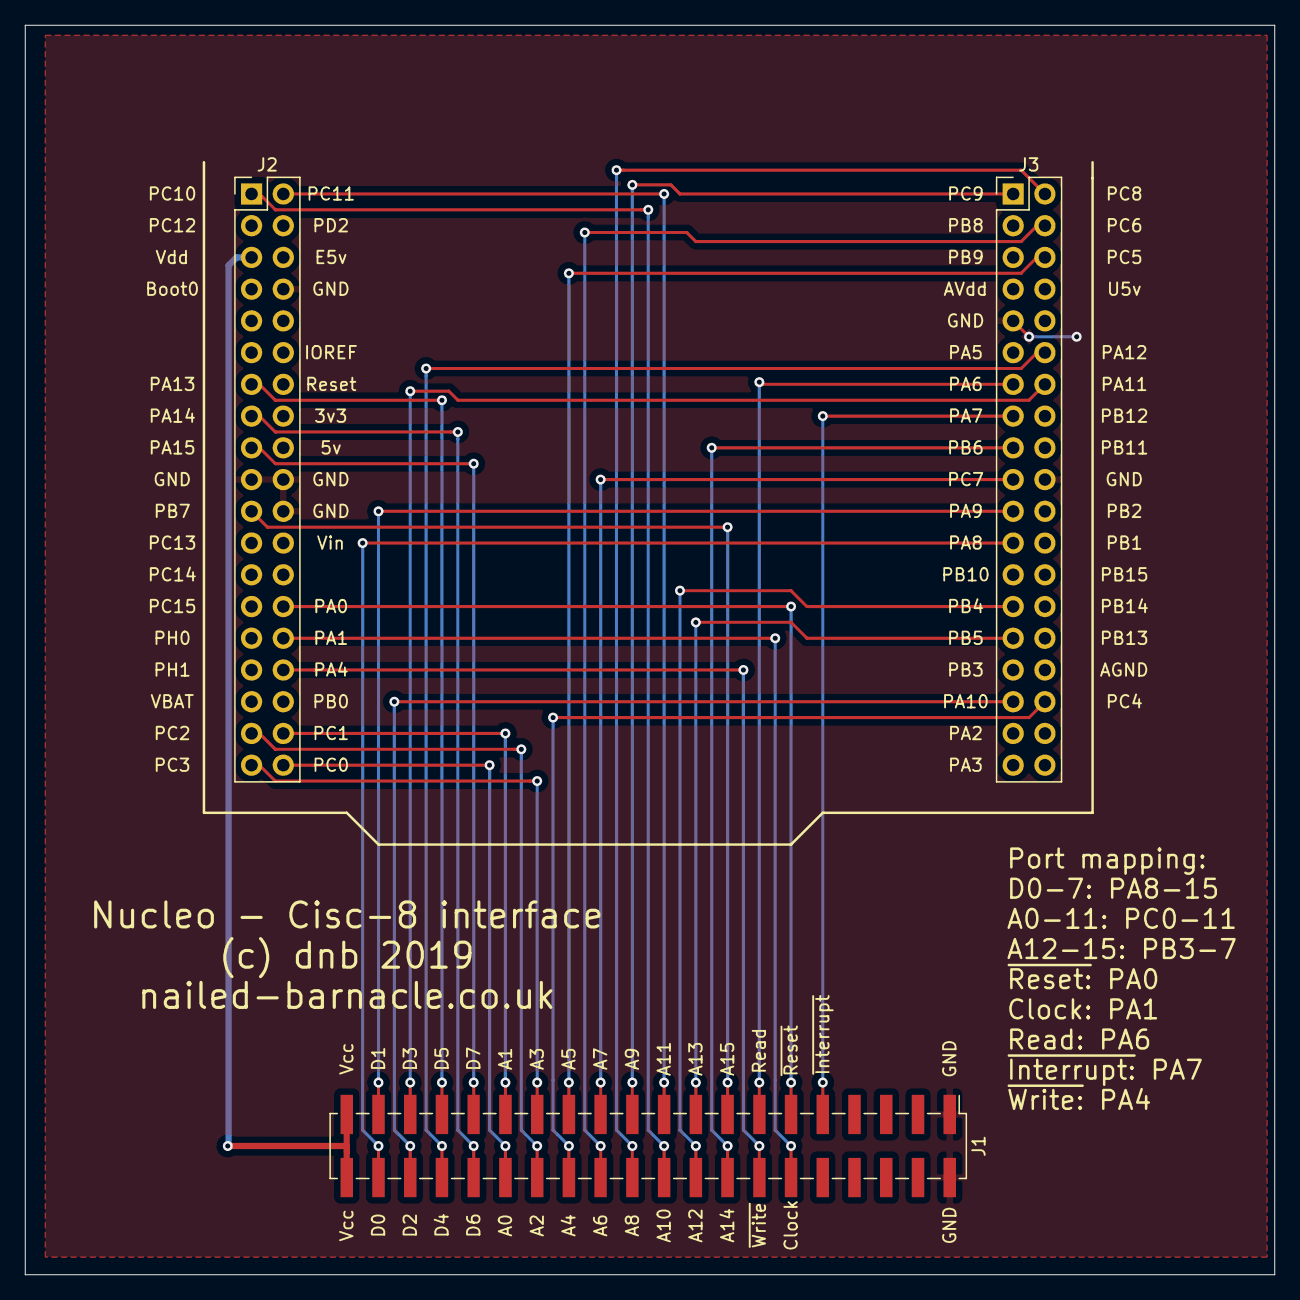
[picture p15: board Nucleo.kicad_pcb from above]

Board: 2 copper layers, 100.0 x 100.0 mm, 3 parts (0 on the bottom side), 31 nets.

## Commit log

2019-07-22 Initial commit
    Hardware design including Kikad schematics, PCB layout, gerbers and BOM
    [Flags.sch, Phase counter.sch, Stack pointer.sch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]
2019-07-28 Added Nucleo interface board
    The Nucleo connects directly to the Cisc-8 and will emulate 16k of
    memory as well as providing clock, reset, and serial i/o capability.
    [Nucleo.kicad_pcb, Nucleo.sch]
2019-08-11 Minor changes to documentation
    Tidied up schematics, corrected a couple of errors in the instruction
    decoder, added pdf of complete schematics
    [Flags.sch, Phase counter.sch, Stack pointer.sch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]
